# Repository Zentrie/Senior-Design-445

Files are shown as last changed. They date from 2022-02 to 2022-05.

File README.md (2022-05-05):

# 445

An autonomous food container dispenser machine. 

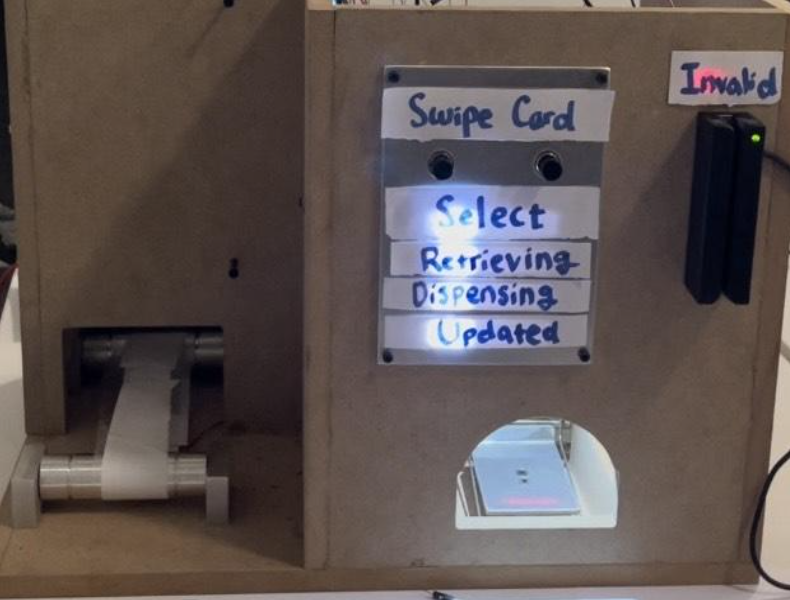
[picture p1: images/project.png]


Team Members:

Ariocie Liang (arliang2), John Kim (jaehank2), Henry Guan (henryg3)

## PROBLEM

Good2Go (G2G) containers are used all throughout dining halls for individuals wanting to take their food to go. The program allows you to trade in an old container for a token, where that token can then be used to trade for a new container. This is a hassle for both parties that handle the entire process. It's very redundant and can be streamlined/improved with mechanical assistance.

## SOLUTION

Our solution involves a token/food container swapping machine that serves 2 main functions:

Have a G2G token, that upon deposit, returns a clean container.
Accept a used container, returning a G2G token or a clean container.
The goal here is to make the process semi-autonomous by removing 2 stages of interaction, as well as speeding up the entire process by doing so.

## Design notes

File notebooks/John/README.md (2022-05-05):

<h1 align="center"> John Kim (jaehank2) Worklog </h1>

* [Summary](#summary)
* [Week of 2022-01-24](#week-of-2022-01-24)  
* [Week of 2022-02-01](#week-of-2022-02-01)  
* [Week of 2022-02-07](#week-of-2022-02-07)  
* [Week of 2022-02-14](#week-of-2022-02-14)  
* [Week of 2022-02-21](#week-of-2022-02-21)  
* [Week of 2022-02-28](#week-of-2022-02-28)  
* [Week of 2022-03-07](#week-of-2022-03-07)  
* [Week of 2022-03-14](#week-of-2022-03-14)  
* [Week of 2022-03-21](#week-of-2022-03-21)  
* [Week of 2022-03-28](#week-of-2022-03-28)  
* [Week of 2022-04-04](#week-of-2022-04-04)  
* [Week of 2022-04-11](#week-of-2022-04-11)  
* [Week of 2022-04-18](#week-of-2022-04-18)  
* [Week of 2022-04-25](#week-of-2022-04-25)  
* [Week of 2022-05-02](#week-of-2022-05-02)  
* [References](#references)

## Summary
This is a notebook outlining the work and progress I made from the start of the project. All the references used are attached under the [References](#references) section at the very bottom.

## Week of 2022-01-24
* **01/25 (Getting Started on the RFA)**:
  * <ins>Objectives</ins>: Get to know the team and familiarize with the problem statement that the team is trying to solve
  * <ins>Overview</ins>: Our team was trying to automate a currently existent service used at the U of I dining halls. However, I was not too familiar with the current system and thus had to search online for how exactly the Good2Go system was managed and what problems there were. I realized that the current system required students to first receive a physical token and find a dining hall employee to exchange it for a new take-out container. After identifying the problems, I started working on the RFA (request for approval) to get started on our project.

## Week of 2022-02-01
* **02/01 (RFA Submission and Starting on Proposal)**:
  * <ins>Objectives</ins>: Get the RFA approved and start working on the proposal
  * <ins>Overview</ins>: The initial RFA post got rejected mainly because our team was not specific about the subsystem requirements. My team and I had a discussion with a TA named Dean Biskup to identify what we were missing in the RFA. I had a general idea of what kind of modules we were going to need for the project such as a motor, ID verification method, UI interface, and power supply components, the specifics were missing out as to how to integrate the entire components. I started looking into the details of each subsystem and was able to design an abstract FSM (finite state machine) with specific modules such as the QR scanner, scale, two sets of motors, display and a card reader. Additionally, I started outlining the criterion of success for our project, which required:
    1. Storing the tokens digitally for each user
    2. Allowing exchange between not only tokens for new containers but also old containers for new containers

## Week of 2022-02-07
* **02/07 (Complete and Submit Proposal)**:
  * <ins>Objectievs</ins>: Complete the proposal for submission
  * <ins>Overview</ins>: Even after getting the RFA approved, the proposal required extra work from each member. I was responsible for the design as well as the tolerance analysis. Our project required a mechanism to dispense exactly one container upon a single request, and the design that I came up with was to have two mechanical arms retracting in a order shown in the image below to dispense a single container while reloading the other containers.  
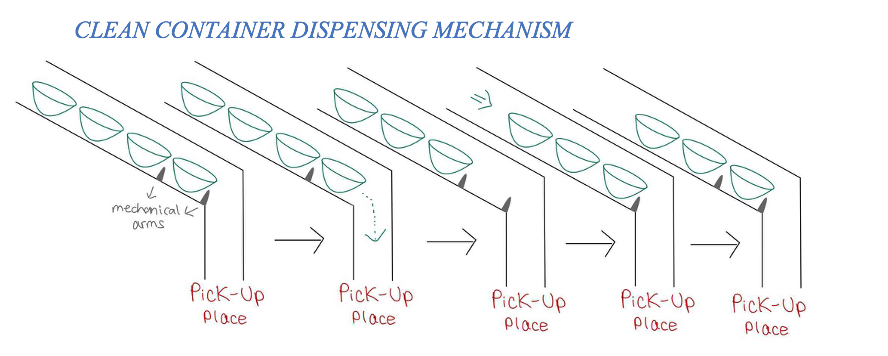
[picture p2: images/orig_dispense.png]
  &nbsp; &nbsp; 

&nbsp; &nbsp; &nbsp; &nbsp; &nbsp; &nbsp; &nbsp; &nbsp; The design for the retrieval system required the machine to parallelize the sensor validtion process with the control subsystem. This was  
&nbsp; &nbsp; &nbsp; &nbsp; &nbsp; &nbsp; &nbsp; &nbsp; to allow the machine to retrieve a returned container the moment it finished validating the container, and thus I made a design to have  
&nbsp; &nbsp; &nbsp; &nbsp; &nbsp; &nbsp; &nbsp; &nbsp; two mechanical arms attached beneath the scale to lift up upon a command from the microcontroller. The image below shows physical  
&nbsp; &nbsp; &nbsp; &nbsp; &nbsp; &nbsp; &nbsp; &nbsp; design of the retrieval system.

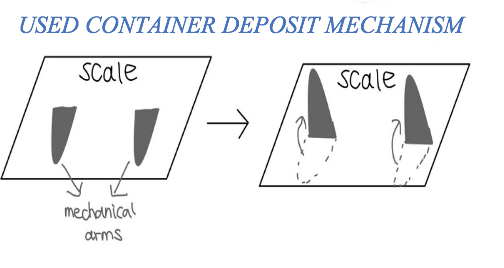
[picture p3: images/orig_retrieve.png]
&nbsp; &nbsp; &nbsp; &nbsp; &nbsp; &nbsp; &nbsp; &nbsp; 

&nbsp; &nbsp; &nbsp; &nbsp; &nbsp; &nbsp; &nbsp; &nbsp; The tolerance analysis was done on the motors using the below equation. Since our project requried a safe and accurate control  
&nbsp; &nbsp; &nbsp; &nbsp; &nbsp; &nbsp; &nbsp; &nbsp; mechanism of the motors, it required measurements on the angular position as well as the RPM (rotation per minute) of the two motors  
&nbsp; &nbsp; &nbsp; &nbsp; &nbsp; &nbsp; &nbsp; &nbsp; we were planning on using. The motor used for the retrieval system needed a closed loop feedback system to be able to rotate properly  
&nbsp; &nbsp; &nbsp; &nbsp; &nbsp; &nbsp; &nbsp; &nbsp; and the speed of the motor was controlled by sending different pulse data. 

&nbsp; &nbsp; &nbsp; &nbsp; &nbsp; &nbsp; &nbsp; &nbsp; 

* **02/11 (PCB Discussion)**:
  * <ins>Objectives</ins>: Discuss the components of the PCB and general pin layout
  * <ins>Overview</ins>: The PCB required getting the footprints of each module our team was planning on using. This meant that we had to decide on the specific modules we were planning on using to get an idea of what kind of pin layouts the schematic would use. There was still some confusion between the exact components we needed, and thus I had worked on finalizing on what materials we needed. All the power and ground wires (VCC and GND) were ignored in the above consideration and only the digital and analog pins are discussed below. Regardless of the model number, the push buttons as well as the motors were going to have 1 data pin. The QR scanner was going to utilize a UART serial communication using the RX (receive) and TX (transmit) pins. The load cell had its own pin layout from the datasheet, but required an amplifier that essentially used serial clock and one data pin. The card reader was going to be connected to the microcontroller through a USB cable, and the power supply was going to utilize a voltage regulator to convert from 12V to 5V. Lastly the LEDs needed 6 to 7 pins, so using a mux was able to cut down the pin numbers to have 3. The below image shows the final schematic layout with the footprints.

<p align="center">
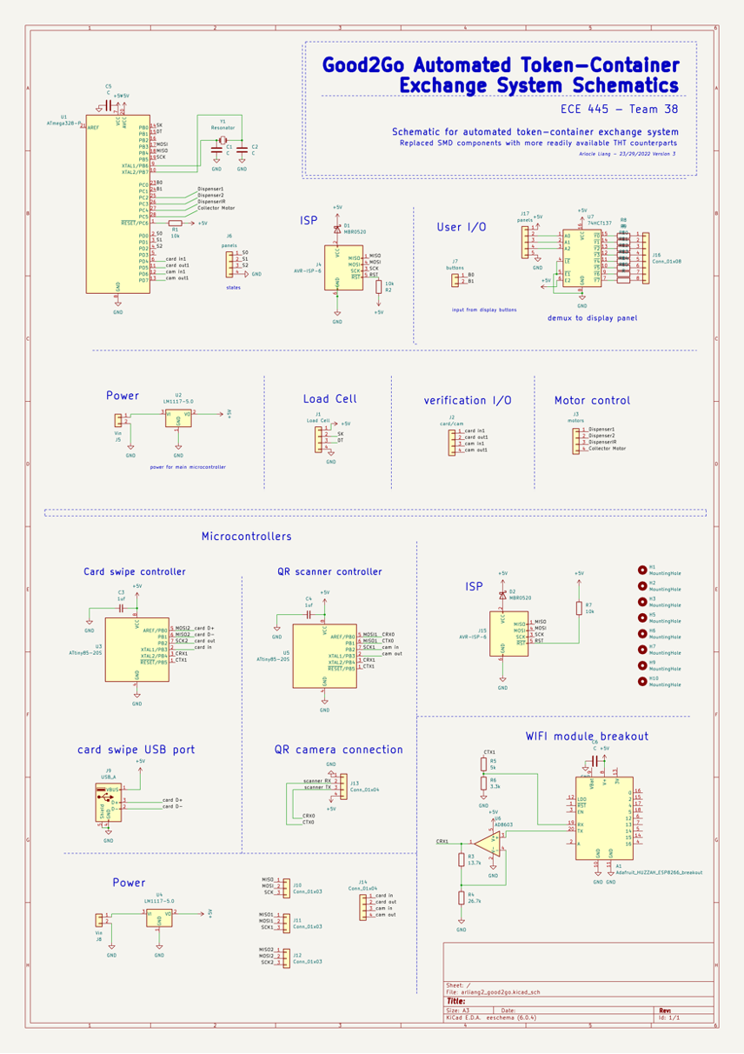
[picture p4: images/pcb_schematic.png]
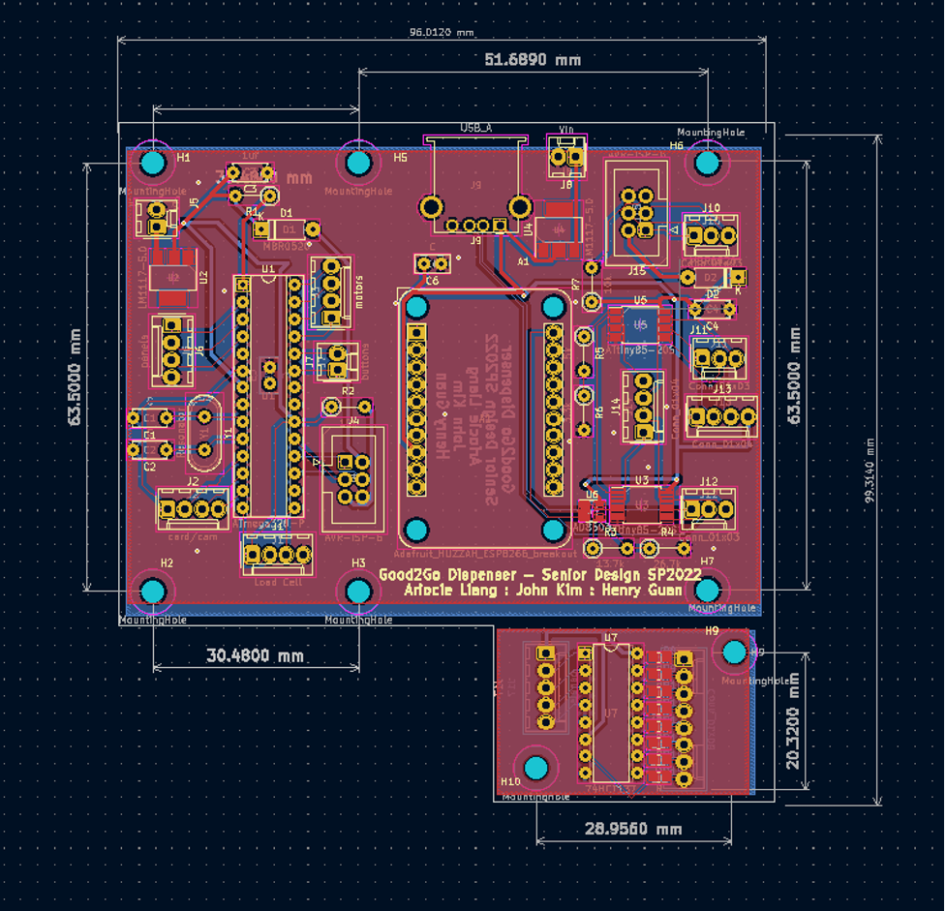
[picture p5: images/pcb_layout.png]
 &nbsp; &nbsp; &nbsp; &nbsp; &nbsp; 
</p>

<p align="center">
 <strong>PCB Layout (Left), PCB Schematic (Right)</strong>
</p>

## Week of 2022-02-14
* **02/16 (Design Document)**:
  * <ins>Objectives</ins>: Finish writing design document for initial submission
  * <ins>Overview</ins>: This week, I mainly focused on writing several parts of the design document. Not only did I add more details for each subsystem and incorporate the design changes we made as a team, but also worked on the Requirements and Verification table. A lot of the requirements for the project required correct mechanical execution that heavily depended on the software code. Thus, some of the verification methods included utilizng the serial monitor for debugging purposes.

## Week of 2022-02-21
* **02/21 (Design Document Check)**:
  * <ins>Objectives</ins>: Check the initial design document submission with our TA
  * <ins>Overview</ins>: After the initial submission of our design document, we received feedback on both the writing requirements as well as the technical aspects. There were a few grammatical errors, but it was mostly about the entire structure of the paper. I revised the format of the document to follow the example paper given on the course website. Additionally, the tolerance analysis needed a bit more work as now I realized that the angular position required to go beyond 90 degrees regardless of the RPM to correctly retrieve the returned container.

* **02/23 (Changes to Design Document)**:
  * <ins>Objectives</ins>: Final submission of design document
  * <ins>Overview</ins>: Made the final changes outlined during the design document check and went over all the small writing details such as the TOC (table of contents) and paging rules. The block diagram also needed changes as we had to specify whether the type of data line was digital or analog. The power supply lines also need specifications as to what voltage it required (e.g. 12V or 5V or 3.3V). The below block diagram reflects the final changes made.

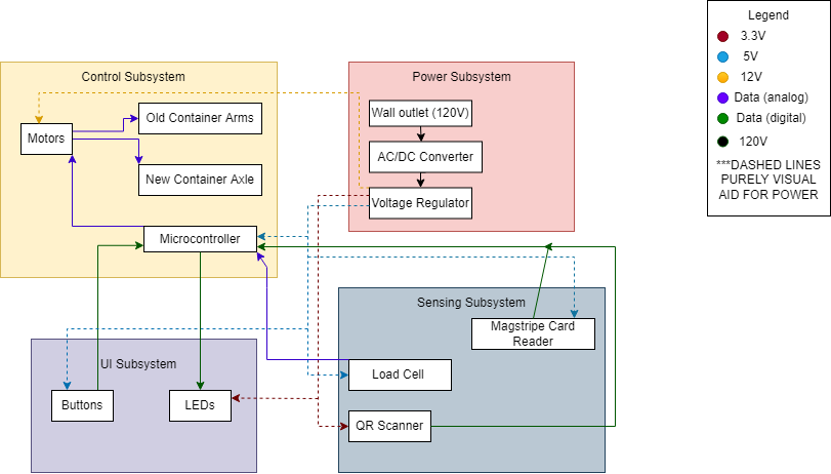
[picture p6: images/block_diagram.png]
&nbsp; &nbsp; &nbsp; &nbsp; &nbsp; &nbsp; &nbsp; &nbsp; 

* **02/27 (PCB Parts)**:
  * <ins>Objectives</ins>: Finalize on PCB parts
  * <ins>Overview</ins>: After acquiring the footprints of each module for the PCB schematic, we had to order the right parts to actually connect to the PCB components. I went through a lot of design considerations such as between servo and stepper motors. In the end, I decided on certain parts like the continuous and non-continuous servo motors as well as acquiring a specific barcode/QR scanner from WaveShare.

## Week of 2022-02-28
* **03/04 (Software Motor Code)**:
  * <ins>Objectives</ins>: Start on writing the software code for motors
  * <ins>Overview</ins>: Because we were dealing with two different types of servo motors (continuous and non-continuous), they were operating in different modes and thus needed different code to run the two. As most of the parts were currently not available for actual testing because they were either still being shipped or being used by the machine shop for the physical design, I had written code for simply testing whether the motors were working or not. The two peices of code that I ran were based on position data and pulse data. This is when I realized we had a malfunctioning continuous motor as it wasn't even getting powered on. I notified my team members and ordered a new component.

## Week of 2022-03-07
* **03/07 (Finish Pseudocode)**:
  * <ins>Objectives</ins>: Finish Pseudocode for the entire project with all sensors
  * <ins>Overview</ins>: Even after getting the individual components working, integrating would add a lot of changes to the written code and so I decided to first work on the general state machine of the project. This way, all the code that I would write for each control and sensor module would take into account the type of input and output they need to be receiving and sending. The below image that I made shows the different state transitions. The initial state corresponds to the idle state of the machine waiting for a card swipe. Only then would the machine activate and start executing other exchange processes.

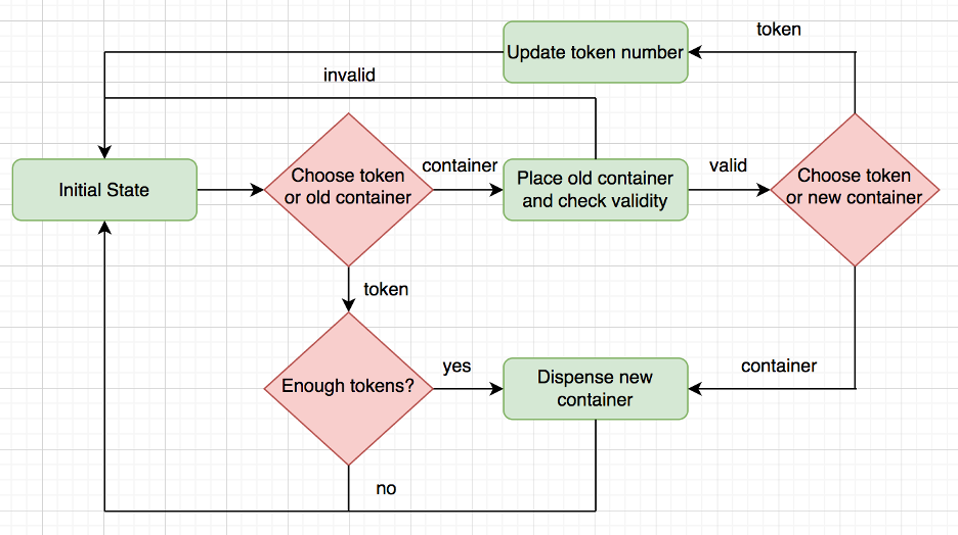
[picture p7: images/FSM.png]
&nbsp; &nbsp; &nbsp; &nbsp; &nbsp; &nbsp; &nbsp; &nbsp; 

* **03/10 (Machine Shop Design)**:
  * <ins>Objectives</ins>: Provide design schematic for the machine shop
  * <ins>Overview</ins>: Since our project was creating a physical product without any basis to automate a currently existing service, there were complex design schematics we had to create to hand off to the machine shop. Only then would they be able to actually build what we had intended. I started looking into the specs of the different modules we bought as these were critical in determing the exact orientations and placements of the sensors. For example, the QR scanner required a specific tilt tolerance and limited FOV (field of view). Also since our machine had to be downscaled compared to what we had originally planned, we had to effectively make use of the space. The below diagram shows the design specifications my team and I made for the machine shop.

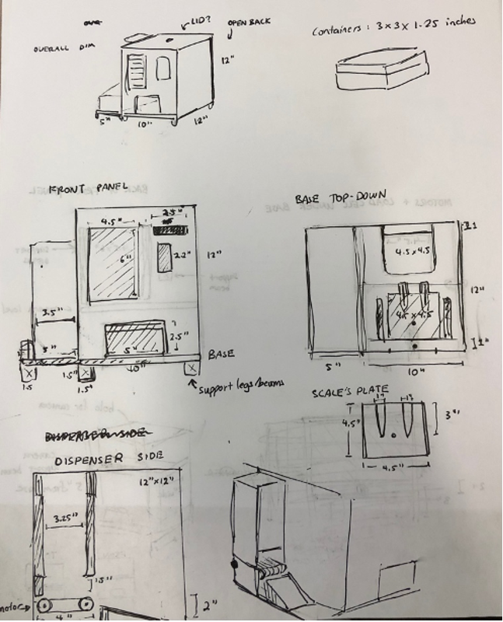
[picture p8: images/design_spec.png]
&nbsp; &nbsp; &nbsp; &nbsp; &nbsp; &nbsp; &nbsp; &nbsp; 

## Week of 2022-03-14
* **03/15 (Finalizing on Parts)**:
  * <ins>Objectives</ins>: Finish ordering all parts required for the project
  * <ins>Overview</ins>: After buying all the big components of the project including the QR scanner, card reader, load cell, and motors, there were still a few other elements we needed. We had to buy different types of LEDs for the status messages as well as an amplifier as the load cell may give out weak signals that are hard to perform a digital read on.

* **03/17 (Machine Shop Order Check)**:
  * <ins>Objectives</ins>: Give all components needed to machine shop for completion of the physical design
  * <ins>Overview</ins>: Despite the design schematic with all specs labeled out, the machine shop required all components in hand to completely finish off the physical design. Thus the continuous motor that I had found defective had arrived this week, and needed to hand that off along with the LEDs to get our actual design finished. The below images show what our machine looked like right after the machine shop had finished making it.

<p align="center">
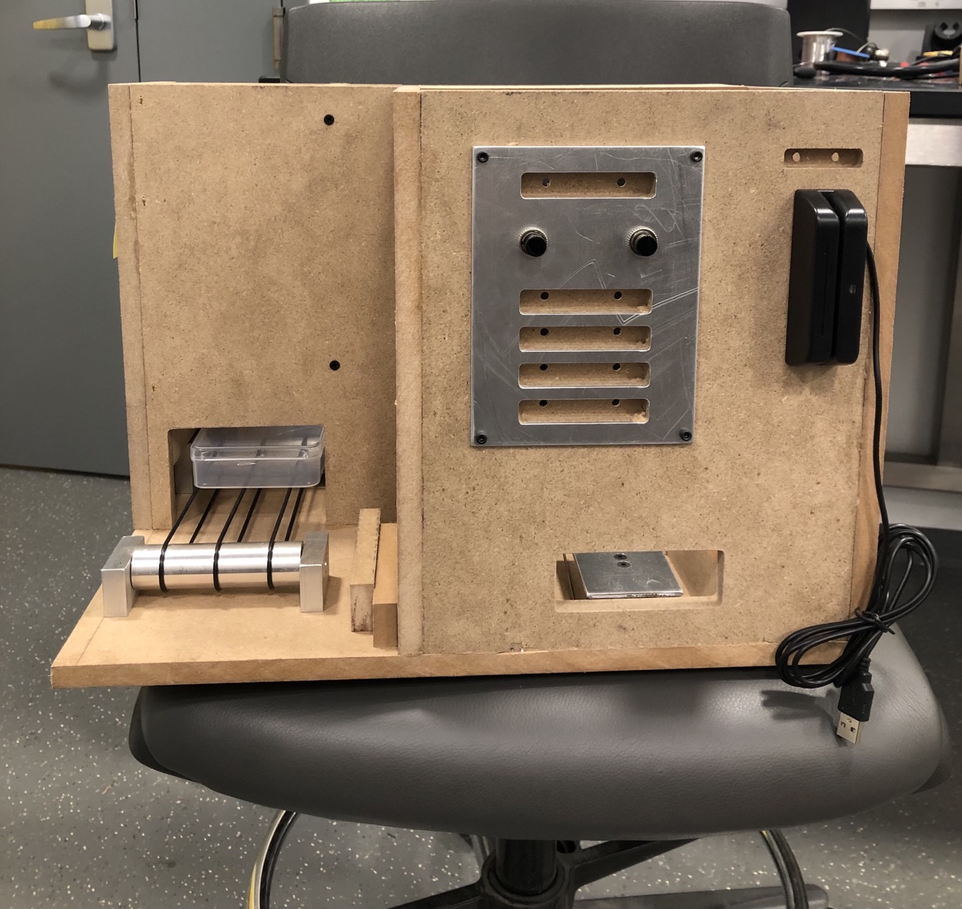
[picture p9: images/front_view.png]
 
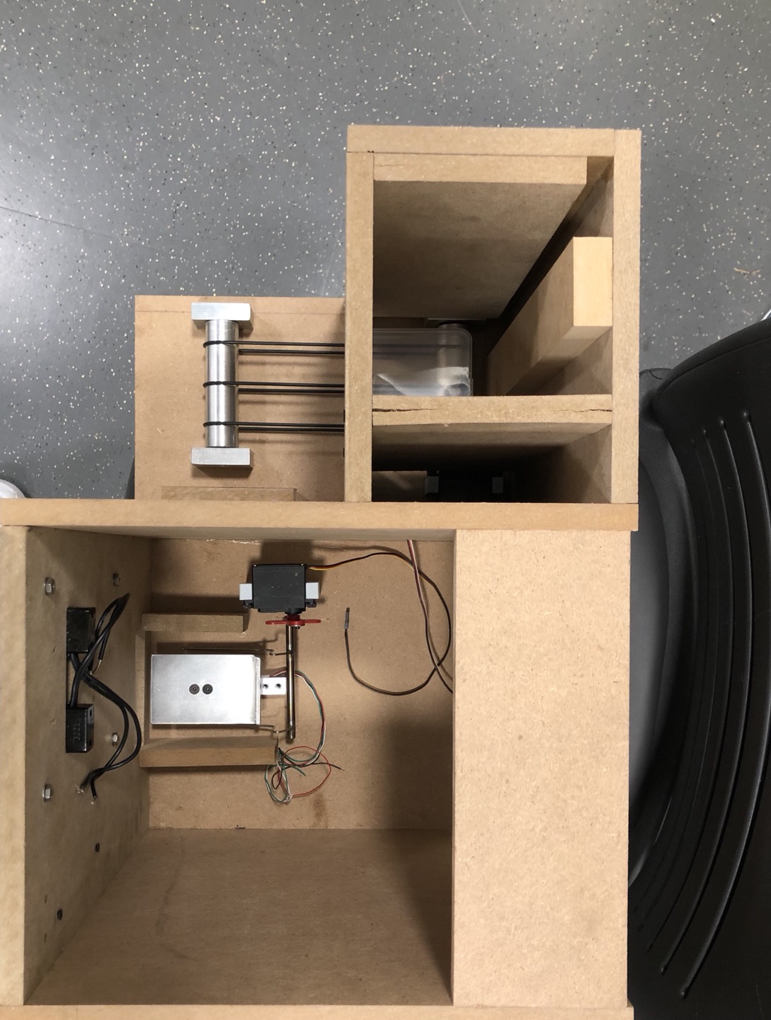
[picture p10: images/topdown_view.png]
 
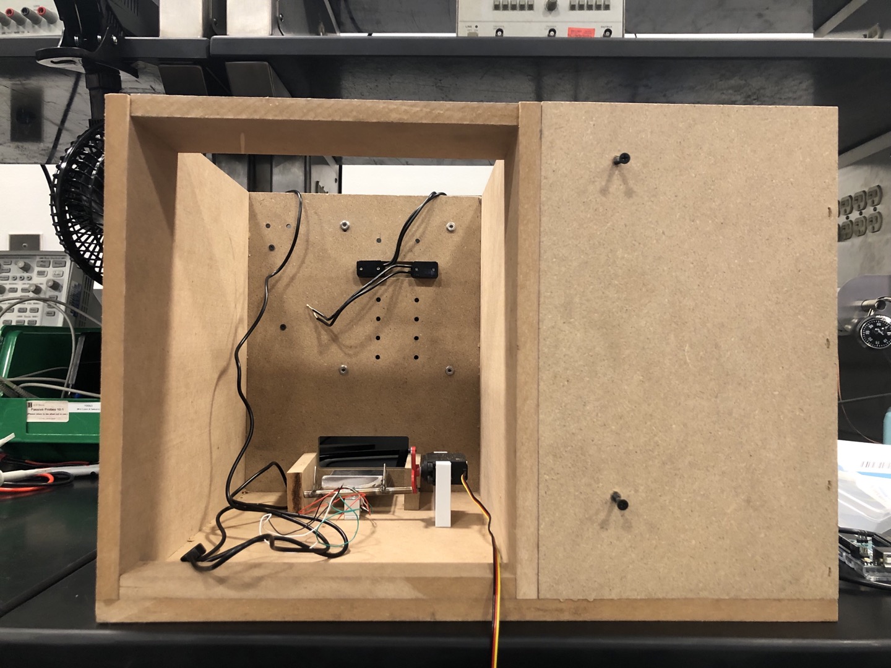
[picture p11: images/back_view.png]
 
</p>

<p align="center">
 <strong>Front View (Left), Top-down View (Center), Back View (Right)</strong>
</p>

## Week of 2022-03-21
* **03/21 (Software FSM Code)**:
  * <ins>Objectives</ins>: Finish the pseudocode for FSM
  * <ins>Overview</ins>: The individual modules still required their own code to actually work, but I made separate helper functions corresponding to different sensor modules. Thus whenenver the FSM required a certain execution of a module, I would call the appropriate functions (e.g. QRread()) that were at this point in time void functions without any lines of code. The FSM code was written first to get an idea of the logic flow and which tasks had higher priority compared to others.

* **03/26 (PCB Testing & Revision)**:
  * <ins>Objectives</ins>: Testing and revising the PCB order
  * <ins>Overview</ins>: I tried helping out with some of the PCB testings while mainly working on the software side. I realized that despite the individual software testing that I have been doing using Arudino uno and a USB host shield, the PCB had to achieve its full functionality as soon as possible to be incorporated into our project. I mainly helped out with soldering the parts and also probing each component to see if there were any faulty chips or wrong connections made within the board itself.

## Week of 2022-03-28
* **03/28 (Individual Progress Report):**
  * <ins>Objectives</ins>: Work on individual progress report for submission
  * <ins>Overview</ins>: I put a short pause on the software and pcb work to work on writing up my individual progress report. This report includes all the personal work I had done so far along with some of the software code I had written.

* **03/29 (Software Servo Motor Code)**:
  * <ins>Objectives</ins>: Finish the code for both continuous and non-continuous servo motors
  * <ins>Overview</ins>: Now that I had the initial code written for both the FSM and the motors, I worked on finishing up the codes for the motors to actually work with the intended design of our machine. The requirement was that the non-continuous motor that was responsible for the retrieval system required angular position data as well as the speed at which it rotates. Initially I had tried getting the motor to rotate slighly below 90 degrees with fast speed to "throw out" the returned containers but turned out to be a bit unsuccessful as it was getting too unsafe. The final testing gave a good result for rotating to 110 degrees witha delay of 10ms for each positional write. </br> </br> The continuous motor, on the other hand, had to go through some tuning process. Although sending a pulse of 1.5ms should have technically stopped the motor, it wasn't doing so and thus I used an adjustment screw and a potentiometer with PWM (pulse width modulation) to find the exact pulse for stopping. I also had to adjust the duration in which the continuous motor ran as it didn't have any closed loop feedback system. The below image shows the piece of code for the above behaviors. 

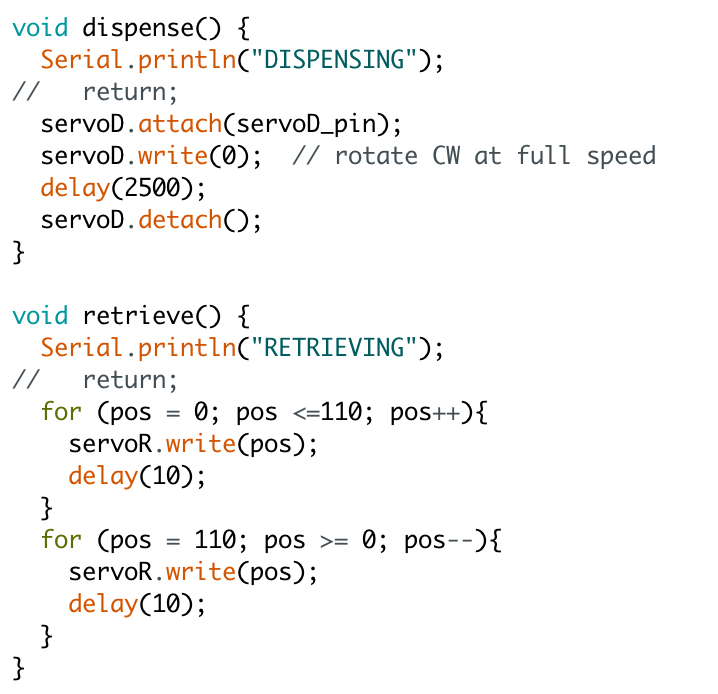
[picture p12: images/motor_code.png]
&nbsp; &nbsp; &nbsp; &nbsp; &nbsp; &nbsp; &nbsp; &nbsp; 

* **04/02 (Software Push Button Code)**:
  * <ins>Objectives</ins>: Software code for the two push buttons
  * <ins>Overview</ins>: The two push buttons that we were using for the project was slightly different than the normal push buttons with 4 legs. The push buttons that we had only had two legs and were operating in maintain-contact mode. This meant that the push button maintained whatever status it was before until another press was made. For example, the data pin for the push button will continuously read OFF (0) until a press is made at which the pin will now continuously read ON (1). The code was written such that it registers the initial button press and only measures the change in the states when needed. This method allowed other processes with higher priority such as the USB task and the UART communication to run without any delay.

* **04/03 (Hardware Push Button)**:
  * <ins>Objectives</ins>: Push Button Issue and Hardware
  * <ins>Overview</ins>: One problem with the push buttons was that the two legs had different types of wires, and needed extra soldering to fit into our PCB. I had notified my teammates about this and was able to get a small board layout to add different wires for the push buttons. The testing of the push buttons were done through a serial monitor to constantly check for the pressed state. However one major issue that I faced was that the buttons were left in a floating state and thus had to add a pull up resistor to define the logic states of the two buttons. The right image below shows the faulty behavior I got, and the left image shows the correct behavior of switching states upon a press.

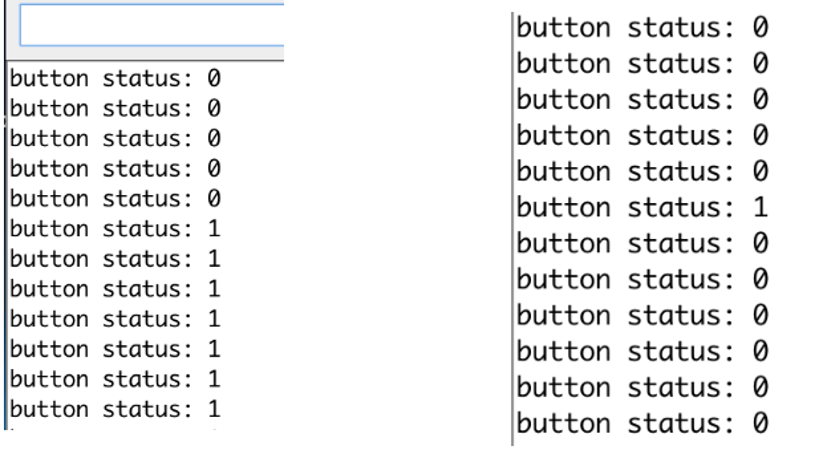
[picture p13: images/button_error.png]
&nbsp; &nbsp; &nbsp; &nbsp; &nbsp; &nbsp; &nbsp; &nbsp; 

## Week of 2022-04-04
* **04/04 (Software Motor Debugging)**:
  * <ins>Objectives</ins>: Non-continuous servo motor debugging
  * <ins>Overview</ins>: When running my software code on our actual machine, I started noticing a weird behavior of one of the motors that we were using when powered up. The normal executions of the motors were fine, but only in the beginning, the motor would shoot up to a 90 degree position when we required it to stay at 0 degrees until it received commands from the microcontroller. After doing some searching, I found out that the motors drew a lot of power and thus required a separate power supply. The solution that I came up with was to have another battery pack of 5V and also add a capacitor in the circuit. Lastly, I sent some initial data commands to the motors on start up to ensure no erratic behaviors were made.

* **04/07 (Software Load Cell Code)**:
  * <ins>Objectives</ins>: Software code for load cell
  * <ins>Overview</ins>: I started working on the software code for the load cell, and realized I had to go through some calibration process. Most scales already come with the calibration done, but the load cell itself had to be manually calibrated for accurate weight measurements. Since our machine had to weigh very light food containers, the below code was written with the use of an amplifier to adjust the calibration factor. The process included placing a known weight onto the load cell and constantly adjusting the calibration factor until the measurement was within a small margin of error.

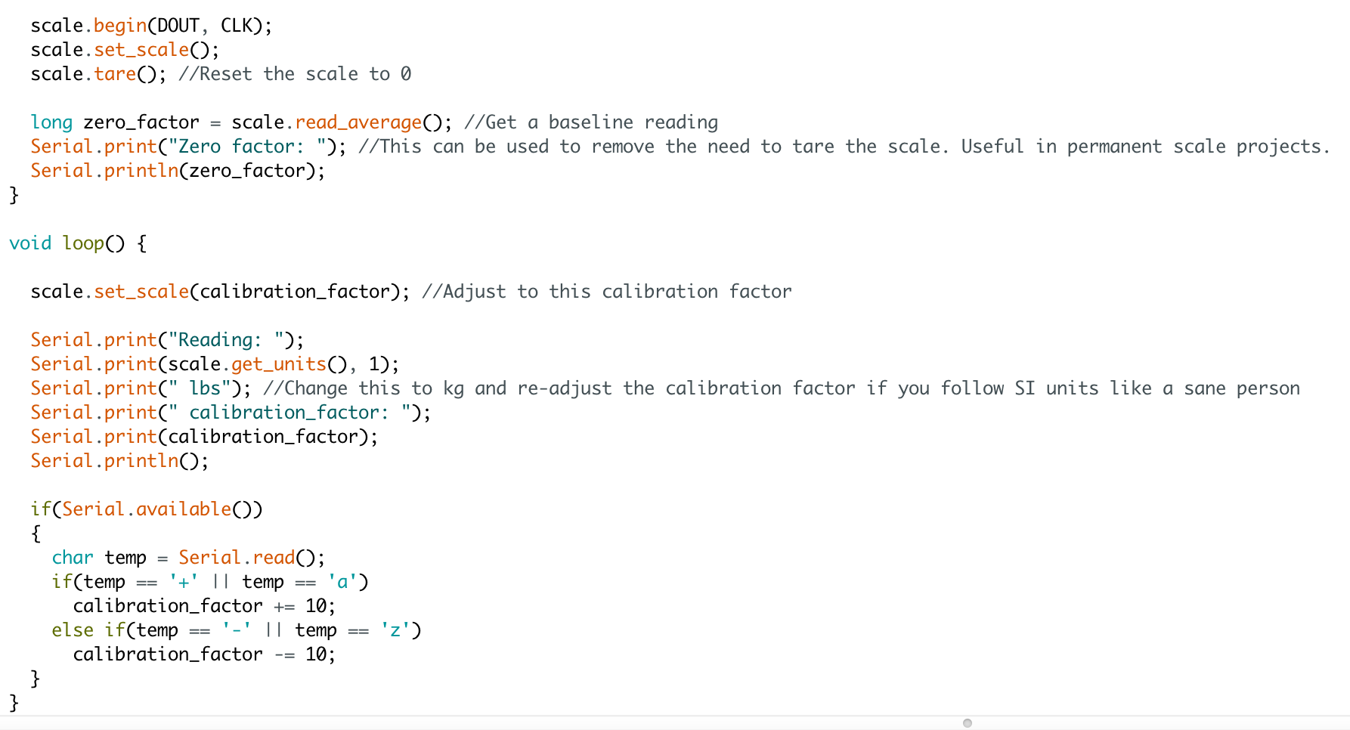
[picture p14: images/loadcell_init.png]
&nbsp; &nbsp; &nbsp; &nbsp; &nbsp; &nbsp; &nbsp; &nbsp; 

* **04/08 (Software Load Cell Code)**:
  * <ins>Objectives</ins>: Software code for load cell continued
  * <ins>Overview</ins>: After the initial calibration was completed, I started working on actual weight measurements within the software. Since the load cell was calibrated for reading small weights, even small small pressure onto it by human contact made extreme fluctations for the readings. Thus I had introduced some delay in the loadcell measurement to start reading weight data until the returned container was fully placed and succeeded in the QR scanning. I then averaged out the weight readings to get an accurate measurement.

* **04/09 (Software Load Cell Complete and Starting QR Code)**:
  * <ins>Objectives</ins>: Load cell wrap up and starting on software code for QR
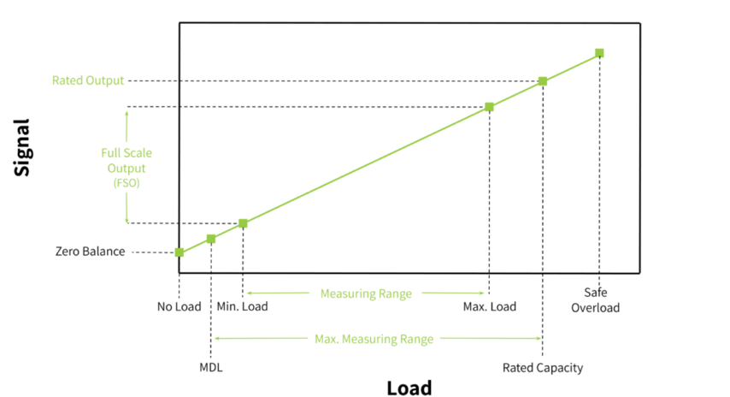
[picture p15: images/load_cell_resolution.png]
  * <ins>Overview</ins>: The last part of the loadcell code required coming up with weight thresholds for the validation process. We required that the returned container shouldn't contain too much food waste. Thus if the container weighed more than 7g compared to its base weight, we would have to reject the container. I set a weight threshold of 10g as the base weight of the container turned out to be approximately 3g. The exact resolution of the loadcell directly links to the sensitivity and accuracy. Thus using the graph below, I was able to calculate the minimum weight measurable by dividng the maximum load by the number of divisions to get about 0.03g. </br> &nbsp; &nbsp; &nbsp; &nbsp;   </br> The QR scanner module supported UART serial communcation. Thus I had to make a connection between the RX (receive) and TX (transmit) pins between the host (microcontroller) and the device (QR scanner). After some trial and error, I was actually able to get some raw readings of the QR scans.

## Week of 2022-04-11
* **04/11 (Software QR Complete)**:
  * <ins>Objectives</ins>: Complete software code and testing for QR scanner
  * <ins>Overview</ins>: Even though I was able to get the QR code readings using the module, there were several issues that I had to fix. One was that the reading values kept changing even for the same QR code. I realized that there were two different types of QR codes, dynamic and statc. Dynamic QR codes had their encoded information change upon creation as it was a redirection to a URL whereas static QR codes had their information fixed. Since our project only required QR codes for validation of the G2G containers, I used static QR codes to read the data. Another issue was that if the returned container sat in the return place for too long, it would get multiple QR scans and fill up the serial communication buffer. Thus next time the machine was used, it gets tricked into thinking that it already has a valid QR scan. To solve this issue, I had to clear the buffer if and only if the container was invalid. I also had to send several UART scan commands to the address of the QR to change some of the default behaviors that were incompatible with the intended design of our project. First change was to set the baud rate from 9600 to 115200 to be synchronized with the card reader, and next was changing the scan mode from sleep to continuous scanning mode. Last step was setting a manual timeout value of 10 seconds to allow users ample time to place and return an old container. After all these configurations, the below code shows what I had used to read in QR data.

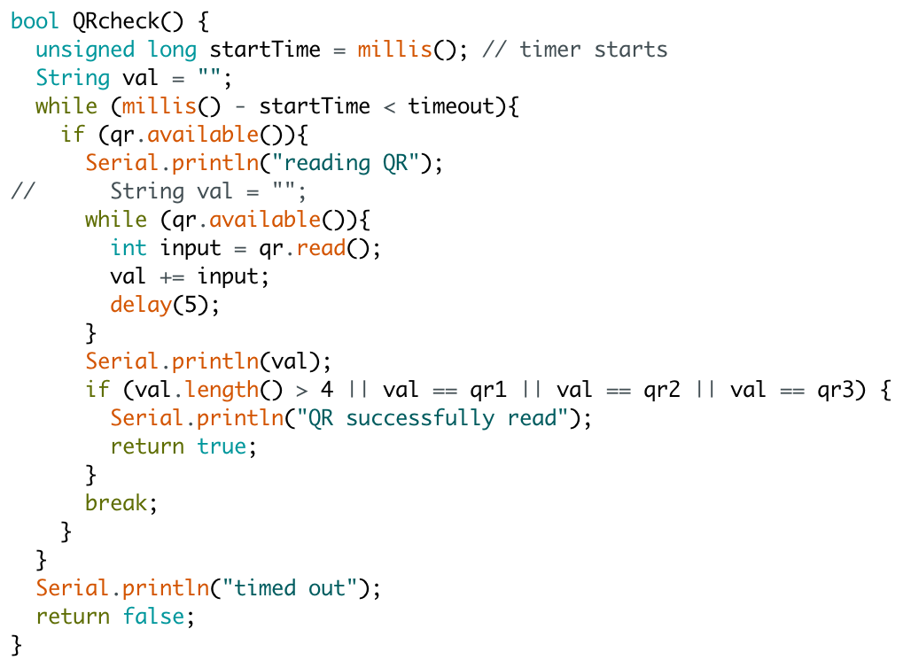
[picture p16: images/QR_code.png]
&nbsp; &nbsp; &nbsp; &nbsp; &nbsp; &nbsp; &nbsp; &nbsp;  

* **04/12 (Software Card Reader Code)**:
  * <ins>Objectives</ins>: Software code for usb magnetic card swiper
  * <ins>Overview</ins>: I started working on the card swiper but spent numerous hours just debugging to get it to work. This was because the card reader was a HID device and had complex USB protocols that I had to go through. The initial model we were using was a MSR123 card reader. As it failed to initialize, I started looking into the product ID as well as the vendor ID and saw a mismatch between what my computer had detected and what my software code had detected. It was failing to retrieve the device descriptor for the specific USB device. I tried making tweaks in the code to store larger bits for the ID as there was a huge mismatch, but no sort of available driver code was able to get the card initialized.

* **04/13 (Card Reader Code Failure & Debugging)**:
  * <ins>Objectives</ins>: Final debugging of the card reader
  * <ins>Overview</ins>: After multiple attempts, I went line by line within the Arduino library to find the point of failure, and identified it to be in the below code. When I declared a USB object within the software, it went through a list of initialization processes to find the device descriptor and storing the end-point address of the device. However it was unable to do so, and I realized that I either had to write a separate driver code (which was impossible with the time constraint I had) or find another HID device compatible with existent driver codes.

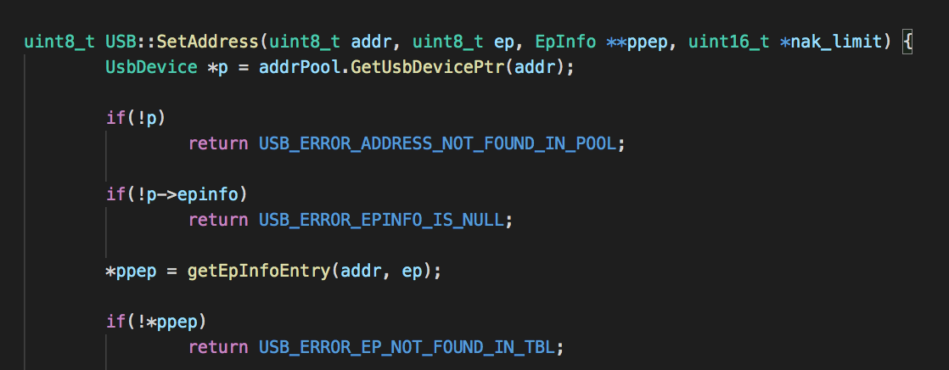
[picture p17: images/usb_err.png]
&nbsp; &nbsp; &nbsp; &nbsp; &nbsp; &nbsp; &nbsp; &nbsp;  

* **04/14 (Card Reader Alternative Solution)**:
  * <ins>Objectives</ins>: Design consideration for the card reader
  * <ins>Overview</ins>: After multiple failures with the card reader, I started thinking about different alternatives. Many teams have been using a RFID tags for ID verification and I also thought about moving to this method. However not only did this incur additional cost as well as delaying the progress with delivery time, it didn't accomodate the intended design of our machine as we wanted it to be available exlcusively to the U of I students using their iCards. Using RFID cards meant that the project was just a proof of concept that has very little practical use as it meant all students would have to purchase a RFID tag. Thus I decided to stick with a card swiper but looked for different models.

* **04/15 (Card Reader MSR90)**:
  * <ins>Objectives</ins>: Card reader code using MSR90
  * <ins>Overview</ins>: The unsuccessful attempts with MSR123 led me to try with another model called MSR90. Forunately after some tweaking, I was able to get the card reader to initialize. One major modification I had to do was so that it would read all different kinds of magnetic stripe cards, but only parse the data for iCards (and not credit cards, etc). This was done by modifying the interrupt response of the device. Card readers act similar to USB HID Keyboard device descriptor as it responds to both key up and key down interrupts. The image below shows the different interrupts that a card swipe and keyboard responds to. The card reader also responded to presses of special key characters like SHIFT and CAPS, which wasn't what I wanted for the project. Magnetic cards usually have three tracks and each track is separated by some special character, which was why the interrupt was happening for RIGHT SHIFT and so on. After getting rid of some of the interrupts, I was able to read in actual data from each card swipe.

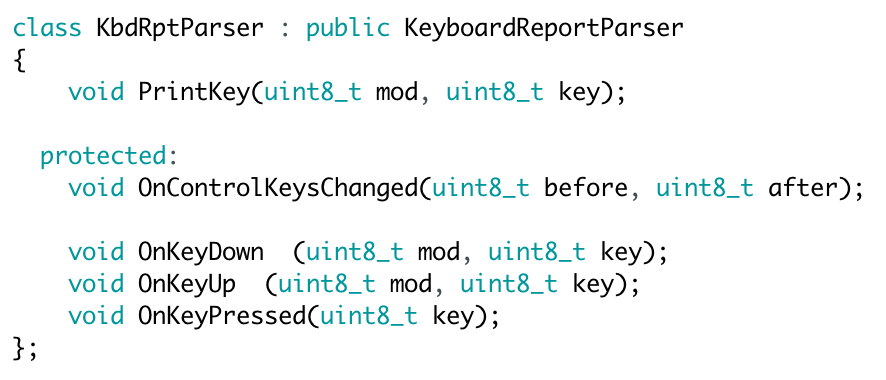
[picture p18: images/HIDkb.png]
&nbsp; &nbsp; &nbsp; &nbsp; &nbsp; &nbsp; &nbsp; &nbsp;  

* **04/16 (Software Card Reader Complete)**:
  * <ins>Objectives</ins>: Finish up the software code for magnetic card reader
  * <ins>Overview</ins>: The last step of the card reader required data parsing. Because the card swipe was sending three different tracks of information, I had to identify which track was relevant and which data to parse. After the final parsing I was able to identify each iCard swipe to be of a CARDHOLDER/UNIVERSITY card as well as reading in the UIN (unifersity identification number).

* **04/17 (Software Code Integration)**:
  * <ins>Objectives</ins>: Integrate all software codes
  * <ins>Overview</ins>: After individual testing of each module, I had to put these back into the original FSM code that I had written to get the entire functionality of the machine working. Since we were using on-chip memory to store user information such as the number of available tokens, I created a student struct for each user as below. Each student is identified by his or her UIN along with the name, and the data stores the number of tokens as well. The final integration and output of our machine is posted on YouTube, and the link is shown under 04/24 (Final Wrap Up and Enclosure) in section [Week of 2022-04-18](#week-of-2022-04-18).

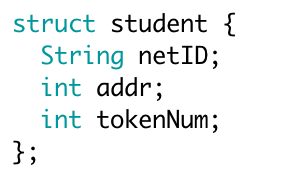
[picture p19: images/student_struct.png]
&nbsp; &nbsp; &nbsp; &nbsp; &nbsp; &nbsp; &nbsp; &nbsp;  

## Week of 2022-04-18
* **04/19 (LCD Display and LED)**:
  * <ins>Objectives</ins>: Design decision between LCD and LEDs and finish software code for status messages
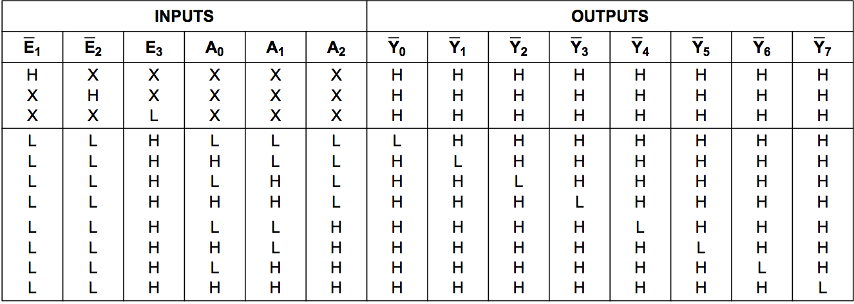
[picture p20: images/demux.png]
  * <ins>Overview</ins>: Initially I thought of having a LCD display screen for UI subsystem, but realized that the machine was intended to behave in a similar manner to that of a normal vending machine, which meant that there was little to no information to convey to users. Most information was abstracted away for security reasons and thus the final design decision I made was using LED status messages. This was done using LEDs for 6 different states and using a multiplexer to cut down on the number of wires. The table below shows the 8-to-1 demux outputs based on the three select pins A0, A1, A2. </br>   </br> The LEDs were then controlled within the code using a helper function shown below.

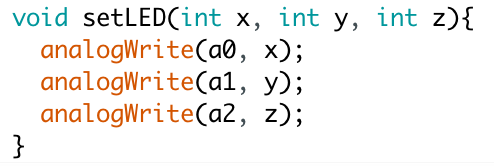
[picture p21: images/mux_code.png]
&nbsp; &nbsp; &nbsp; &nbsp; &nbsp; &nbsp; &nbsp; &nbsp;  

* **04/22 (Mock Demo)**:
  * <ins>Objectives</ins>: Mock demonstration with our TA
  * <ins>Overview</ins>: We did our mock demosntration just in front of our TA and received feedback on certain parts. We were told to have an enclosure for our machine so that all components are well hidden from an outside user. The functionality was mostly achieved, but there were some minor things that I still had to work on.

* **04/23 (Final Debugging and LED Status Message)**:
  * <ins>Objectives</ins>: Finalize and complete on the functionality part of the project
  * <ins>Overview</ins>: Most of the software and hardware components were complete at this point, and I had to ensure that everything was working as expected for the final demo. I ran through several different testcases for our machine and also wrote the status messages on top of the LEDs.

* **04/24 (Final Wrap Up and Enclosure)**:
  * <ins>Objectives</ins>: Finalize and complete the entire project
  * <ins>Overview</ins>: Incorporating the feedback we received from the mock demo, we completed the enclosure for our machine so that all things were abstracted away. We also made certain openings for the enclosure so that any "authorized" individuals were allowed to collect returned containers and refill new containers. The below link shows the functionality of our entire project and the two gifs below demonstrate how the sensor and control subsystem work together to complete the retrieval and dispensing system.
  * <ins>YouTube link</ins>: https://www.youtube.com/watch?v=p8fdRb78moU

<p align = "center">


</p>

<p align = "center">
 <strong>Retrieval (Left) and Dispensing (Right)</strong>
</p>

## Week of 2022-04-25
* **04/26 (Final Demo)**:
  * <ins>Objectives</ins>: Complete final demonstration
  * <ins>Overview</ins>: We did our final demonstration in front of our TA, professor Song as well as some other individuals who wanted to attend our presentation.

* **04/27 (Presentation Slides)**:
  * <ins>Objectives</ins>: Work on presentation slides and final report
  * <ins>Overview</ins>: After the final demo was over, there were only two major components left, which were the final presentation and the final report. I took this week to complete some of the design and software components for both the presentation and the report. I also arranged our team meetings to get together and rehearse.

## Week of 2022-05-02
* **05/03 (Final Presentation)**:
  * <ins>Objectives</ins>: Deliver our final presentation
  * <ins>Overview</ins>: Similar to the final demo, we had our final presentation in front of our TA, professor Song, and some individuals who wanted to attend. This took about 20 minutes along with 5 extra minutes for additional Q&A.

## References
* Adafruit, Continuous Rotation Servo - FeeTech FS5103R. [Online]. Available: https://media.digikey.com/pdf/data%20sheets/adafruit%20pdfs/154_web.pdf. [Accessed: 02-May-2022].
* “QR code vs Barcode: Why the difference matters,” Paysley Blog, 10-Feb-2022. [Online]. Available: https://paysley.com/blog/qr-code-vs-barcode/. [Accessed: 03-May-2022].
* “Resistors for led circuits: Resistor applications: Resistor Guide,” EEPower. [Online]. Available: https://eepower.com/resistor-guide/resistor-applications/resistor-for-led/#. [Accessed: 03-May-2022].
* “RFID scanner - full tutorial,” Arduino Project Hub. [Online]. Available: https://create.arduino.cc/projecthub/shubamtayal/rfid-scanner-full-tutorial-6518db. [Accessed: 03-May-2022].
* “Stepper vs Servo,” Tutorial: Stepper vs Servo. [Online]. Available: https://www.amci.com/industrial-automation-resources/plc-automation-tutorials/stepper-vs-servo/. [Accessed: 03-May-2022].
* “Tal221 miniature load cell - cdn.sparkfun.com.” [Online]. Available: https://cdn.sparkfun.com/assets/9/9/a/f/3/TAL221.pdf. [Accessed: 02-May-2022].
* University Housing, “Good2Go carry-out program,” University Housing. [Online]. Available: https://housing.illinois.edu/Dining/Locations/Good2Go-Carry-Out-Program. [Accessed: 30-Apr-2022].

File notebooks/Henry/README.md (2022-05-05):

# Henry Guan    
# 2022-01-25 -- Formation of Team, RFA, Initial Parts List
- Found group members to form a team, worked on the RFA, as well as formulating a basic parts list with teammates.  
# 2022-01-27 -- Initial RFA Post 
- Completed RFA with teammates and posted to Web Board for approval. RFA was rejected; took TA feedback into account and made revisions to the RFA accordingly. 
# 2022-02-01 -- Discussion with Dean Biskup (TA) 
- Discussed how we can get our project approved with Dean after the third class meeting. Made more revisions to RFA and posted it to the Web Board.  
# 2022-02-07 -- Project Proposal 
- Worked on the proposal with my teammates, creating the block diagram, problem statement, and the RV Tables.
# 2022-02-08 -- Github Repository 
- Created Github repository with my teammates, uploaded initial project files.
# 2022-02-09 -- Project Proposal 
- Completed remaining sections of the proposal and proofread everything afterwards.
# 2022-02-16 -- Design Document 
- Worked on the Design Document, revising the block diagram and the Requirements and Verification, and added more to the Introduction section. 
# 2022-02-21 -- Design Document Check 
- Had our design document check with Professor Schuh before our final design submission and design review. 
# 2022-02-23 -- Design Document 
- Took Professor Schuh's feedback into account and edited the different units, adding to the Requirements and Verification, as well as revising the block diagram and changing our scale to a load cell.  
- Helping out with figuring the circuit schematic with our MCU in our Control Subsystem. 
<p align="center">

</p>
<p align = "center">
<strong> Block Diagram </strong>
</p>

# 2022-02-28 -- Design Review 
- Thought about how the Design Review will go, delegating parts to each teammate for what to talk about, as well as how to address the different kinds of questions we can expect. 
# 2022-03-01 -- PCB Design & Reviews
- Met with my teammates to finalize our PCB footprint design, and incorporated feedback from the PCB Reviews with a TA.
# 2022-03-10 -- Machine Shop Design 
- Met with my teammates to revise machine shop design from the initial conversation. 
  - Agreed to downsize machine 
  - Modified dispensing mechanism from retracting mechanical arms to a conveyor belt
  
- Measured dimensions of our intended container of use, sketching and designing our new machine shop design around the container's dimensions.
<p align="center">

</p>
<p align = "center">
<strong> Physical Design Used for our Machine Shop Contraption </strong>
</p>

# 2022-03-11 -- Machine Shop & Parts
- Met with Gregg Bennett and Skee Aldrich to discuss our revised physical design and get it built. 
- Bought parts from the ECE Supply Center, specifically two servo motors (one continuous, one non-continuous), a demultiplexer, an ATMega328P, and LED diodes.  
# 2022-03-12 -- PCB Order
- Teammates and I agreed to independently order the PCB, as the first round deadline already passed by. 
# 2022-03-17 and 2022-03-21 -- Machine Shop 
- Met with Gregg Bennett to look at initial physical apparatus and left parts with Gregg to continue the build progress. 
# 2022-03-26 -- PCB Testing & PCB Revisions 
- All met up at the lab to complete PCB assembly by soldering all components in, and started to test the PCB.  
- We made a big mistake with the PCB, as we had a lot of wrong parts, particularly resistors, as they were not the right value we initially thought we needed for our PCB to be functional. 
  - We modified our PCB footprint design accordingly, preparing for secound round PCB orders.
- Ordered barcode/QR scanner camera module.
# 2022-03-28 and 2022-03-29 -- Individual Progress Report
- Worked on individal progress report.  
# 2022-04-04 -- Initial Testing 
- Met with John to test motor functionality within our physical apparatus.
- Ordered new continuous servo motor as our original unit was dead on arrival (DOA). 
- Looked into magnetic stripe cards and how data is processed and sent through an MSR 123 USB reader. 
- https://www.tutorialspoint.com/arduino/arduino_dc_motor.htm -- Tried following this tutorial
- https://www.arduino.cc/reference/en/libraries/magstripe/ - Went through some of the libraries for magstripe card readers
# 2022-04-05 -- Machine Shop Revisions
- Met with Gregg Bennett to make modifications to our physical apparatus according to our initial testing from the previous day. 
# 2022-04-06 -- Load Cell
- Met with John to test load cell using our initial software code. Got the load cell to output force readings to our serial monitor in Arduino. 
- https://www.instructables.com/Arduino-Scale-With-5kg-Load-Cell-and-HX711-Amplifi/ -- Tried following this tutorial   
# 2022-04-11 -- Testing & Integration 
- Met with John to independently test push buttons, servo motors, and load cell working. Integrated all three components to work in conjunction with one another. 
- Ordered USB Host Shield to test card reader. 
- https://docs.arduino.cc/built-in-examples/digital/Button -- Tried following this tutorial
# 2022-04-12 -- Second Round PCBs Arrived 
- De-soldered parts from old PCB and began soldering and preliminary testing on second PCB.
- There were issues with power delivery as it was exceeding the intended 5V delivery, so we used a separate external blank PCB board with MOSFETs and capacitors to properly regulate voltage from the DC power supply. 
<p align="center">

</p>
<p align="center">
 
</p>
<p align = "center">
<strong> Voltage Regulator (top) Connected to PCB (bottom) </strong>
</p>

# 2022-04-15 -- Received New Continuous Servo Motor & QR Scanner Testing
- Met with John to test new continuous servo motor in conjunction with the load cell, non-continuous servo motor, and push buttons. 
- Tested out QR scanner. We had a lot of issues with the QR code being not read in as a valid code and figured out that we needed to use a static QR code, rather than a dynamic one. 
- https://docs.arduino.cc/tutorials/mkr-vidor-4000/VidorQrRecognition -- Tried following this tutorial
# 2022-04-16 -- Swap to MSR90 Card Reader
- We were struggling a lot with the MSR 123 card reader, as it was not even initializing as an HID device, so we switched to the MSR 90 card reader, and it was able to successfully read in UIN data from our iCards.
- Integrated the software side for each module and tested the machine as a whole. The software worked for dispensing as well as retrieving.
<p align = "center">


</p>
<p align = "center">
<strong> RETRIEVAL (left) AND DISPENSAL (right) </strong>
</p>

# 2022-04-17 -- PCB Debugging 
- Attempted to integrate PCB with our software, but our PCB was not working. 
- Probed all the components on our board, and found there was a huge voltage drop across components that were on the right side of the board. 
- Determined this voltage drop to be caused by a corroded SMD voltage regulator, which restricted current a lot.
  - Cause of corrosion was due to using water-soluble flux when desoldering from our original PCB
# 2022-04-22 -- Mock Demo
- Conducted our Mock Demo with our TA (Akshat). Tidied up final apparatus and got ready for final demo. 

# 2022-04-26 -- Final Demo 
- Present project in front of our TA (Akshat) and Professor Song. 
- Preparation for final presentation.

# 2022-05-03 -- Presentation
- Present in front of our TA (Akshat) and Professor Song.

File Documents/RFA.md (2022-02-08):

Team Members:

Ariocie Liang (arliang2), John Kim (jaehank2), Henry Guan (henryg3)

## PROBLEM

Good2Go (G2G) containers are used all throughout dining halls for individuals wanting to take their food to go. The program allows you to trade in an old container for a token, where that token can then be used to trade for a new container. This is a hassle for both parties that handle the entire process. It's very redundant and can be streamlined/improved with mechanical assistance.

## SOLUTION

Our solution involves a token/food container swapping machine that serves 2 main functions:

Have a G2G token, that upon deposit, returns a clean container
Accept a used container, returning a G2G token or a clean container
The goal here is to make the process semi-autonomous by removing 2 stages of interaction, as well as speeding up the entire process by doing so.

# SUBSYSTEMS

## Initial State:
The initial state of the machine will be waiting for user input for either an {old container} or a {token}, which is read by the microcontroller

## Display Screen and Buttons:

The display screen along with the button is used to guide the user into selecting one of the two options. The first selection is {old container} and {token} which is used to inform the machine what it’s supposed to expect from the user. In the case of the {token}, the machine will read from the card swipe. The next option that will be displayed is {new container} and {token} which occurs in the event the user returns an old container. Based on the input, the machine will return either a new container or update the token info from the swiped card.

## Sensors:

QR scanner to identify valid containers by reading the food container ID and a wifi module to send it over to the microcontroller. If it is an invalid ID, the machine returns to its initial state. Otherwise, the machine will dispense either a {new container} or generate a {token}
Scale to measure weight so that once it exceeds {container weight + constant}, the machine will not accept the container and will return to its initial state. If the weight is within the threshold, the machine will dispense either a {new container} or generate a {token}
Card Swipe is used to process digital coins instead of physical ones. Each card will hold information of the number of tokens and will get updated for every swipe. If a card swipe is read from the initial state, the machine will dispense a new container

## Microcontrollers:

Microcontroller will keep track of the state transitions and will also be responsible for activating different motors and reading data from the scale, token as well as the food container ID. From the initial state (old container, token), if the user inputs an old container, the microcontroller will take input from the scale and activate the motor to receive the returned old container, and then wait for further user input for {new container} or a {token}. Otherwise if the user selects a token, the microcontroller will process the token and activate the motors to dispense a new container.

## Motors:

Motors will be wired to a pair of arms near the opening of where the user can place an old container. It will be placed on the same surface as the scale (on the bottom of the old container) so that once the motors are activated, it lifts up and acts as the pushing mechanism to deposit the old containers.
A different set of motors wired to two arms (spaced for a single container) will also be used to dispense new containers. Only a single container will be preloaded in between the arms, with the rest being loaded behind this single container at an angle. Upon the activation of the motors, the first arm closest to the drop chute will open first, dispensing the container. That arm will then close, followed by the second arm opening, allowing one container through. That barrier will then close, completing the process of preloading another container that's ready to dispense. 

CRITERION FOR SUCCESS

User should be able to start the process by pressing a button, selecting whether they are depositing a valid token or a used G2G container.
When a valid token is deposited, the machine should dispense a clean container and reset. If token is invalid, return token and reset.
When a G2G container is deposited, the machine should check that the container is valid (has a valid bar code and is not over a set weight limit)
If the deposited container is overweight, the machine waits for the user to pick up the container, clear it out, and set it down again.
Else, it will ask the user to select either a token or a clean container to be dispensed.
the machine will then dispense selected object and reset.
In total the entire process should take a minute per person to complete!

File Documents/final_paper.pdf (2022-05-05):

# Good2Go Automated Token Exchanger (GATEr)

### Ariocie Liang (arliang2) Henry Guan (henryg3) John Kim (jaehank2)

### ECE 445 Final Report, Senior Design, Spring 2022 Team 38 TA: Akshatkumar Sanatbhai Sanghvi May 05, 2022

ii

## Abstract

This project aims to create a product that streamlines and automates a service called Good2Go that is prevalent in the U of I dining halls. The original service provides a container that a student can use to take food to go from the dining halls in exchange for a token or an old container. The design focuses on automating the process of exchanging tokens and containers rather than having a student find a dining hall employee to complete the process. In this report, the project’s design, requirements and verifications, and results are comprehensively detailed. Although there were small shortcomings and issues that affected the ideal final product, our team achieved a proof of concept design that provides a solution to the current problems of the Good2Go system, which is exposed to several security and labor issues.

iii

## Table of Contents

## 1. Introduction

### 1.1 Problem Statement

Since the pandemic began, more and more people have had to become isolated to avoid the spread of COVID-19. As a response to such measures, the U of I dining hall system implemented a token/container exchanging system named Good2Go (G2G) to allow students to take food from the dining halls. The system allows students to exchange an old container for a redeemable wooden token to then exchange for a new container [1]. The current process lacks a unified system across all U of I dining halls and relies heavily on human supervision and interaction. Furthermore, the intermediate process of having to receive a physical token first in order to exchange for a new container causes significant delay in the system when students can directly exchange a new container by returning an old one. The current system also proves to be a hassle for both parties involved in the process since it is too simple to have a single person be assigned to it, but occurs often and spontaneously enough to become bothersome.

### 1.2 Solution

To solve the above problem, we developed a machine that automates the process of exchanging tokens and containers. The machine is capable of storing digital tokens, removing any inconvenience caused by carrying a physical token such as concern for loss. The system not only allows an exchange between old containers and tokens but also a direct exchange between old containers and new containers. The goal of the machine is to transform the process into a semi-autonomous system by removing human to human interactions and also allowing users a choice to select between a digital token and a new container. This improves the efficiency, simplicity, and performance speed of the current G2G container system.

The machine activates upon a card swipe to strictly allow only U of I students for access using their iCards. A QR sensor and a load cell are used to detect validity of the containers using weight measurements and G2G QR code. The front of the machine has LED status messages to show user-friendly instructions as well as push buttons to take user input. Lastly the microcontroller and motors are used to process the internal state of the machine and execute the actions necessary to retrieve or dispense containers and digitally update a user’s token count. The sensors are the main replacement of the human to human interaction with the role of authenticating valid containers and tokens. The validity of each container is defined by its QR code as well as the weight to ensure minimal food waste within the G2G containers.

### 1.3 High Level Requirements

The three high level requirements below outline the successful functionality of the machine:

1. The system should deliver the entire process from receiving an old container or token to dispensing a new container in less than 15 seconds, assuming minimal delay in the user’s action.
2. The system should dispense exactly one new container at a time indefinitely without jamming and should never allow more than one container to be dispensed upon a single request

3. The system must correctly reject invalid G2G containers without QR codes or with weight that exceeds 7g compared to the base weight.

The first high level requirement ensured that the machine could handle a high number of users by leaving ample time to make their selection while minimizing delay to complete the exchange. The next high level requirement ensured that all exchanges were one-to-one; in other words, no user should ever accidentally receive more than one container or receive none due to a mechanical fault in the system. The final high level requirement ensured that fraudulent exchanges with invalid containers were rejected, and only fully validated containers could continue through the exchange process. All three requirements were met by the final design and will be further discussed in Section 2 of the paper.

### 1.4 Subsystem Overview

Figure 1 below outlines the four subsystems used in our machine. The power subsystem supplied 12V to the motors in the control subsystem, 3.3V for the LEDs and 5V to all other components including the microcontroller and sensor modules. The control subsystem had motors receiving different data signals from the main microcontroller to activate the two types of mechanical arms responsible for retrieval and dispensing system. The UI subsystem mainly handled reading user inputs from the push buttons and outputting LED status messages for instructions. Finally, the sensing subsystem was used as a method of validation for both the user and the container. The load cell and QR scanner were responsible for verifying the weight and the QR code of a G2G container while the card reader was placed to authenticate user information through iCards.

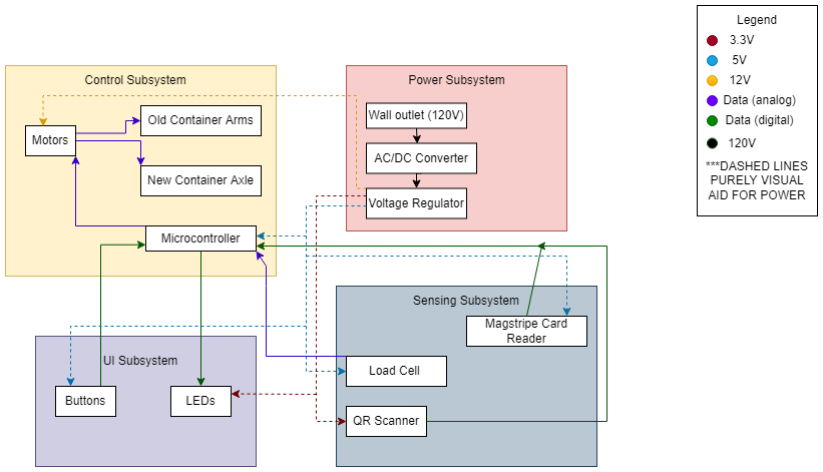
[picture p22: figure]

Figure 1. Block Diagram of the G2G Machine

## 2. Design

### 2.1 Design Procedure

With the current Good2Go system being only a service and not a product, the machine required complex design specifications accounting for different specs of each module. The scanning distance and field of view of the QR sensor required specific distance and tilt threshold from the containers while the load sensors and mechanical arms were placed in conjunction to parallelize the action of validating and retrieving returned containers. The base top-down view in Figure 2 also shows how returned containers are retrieved into an empty bin by the mechanical arms. The most intricate part of the mechanical design was the dispensing system, which required a mechanism to output exactly one container without any faulty behaviors such as physical jamming. This was done using a treadmill system powered by a continuous servo motor with an opening for exactly a single container height (1.25in) as shown in the bottom two diagrams of Figure 2.

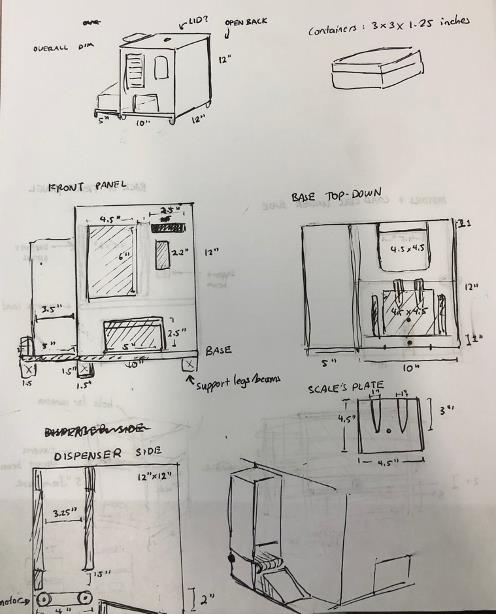
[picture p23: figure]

Figure 2: Design Specification of the G2G Machine

The design procedure also consisted of assigning another layer of state transition to the current G2G system to allow a direct exchange between old containers and new containers. Figure 3 below illustrates the finite state machine of the logic flow in which the initial state corresponds to the machine’s idle state waiting for a card swipe.

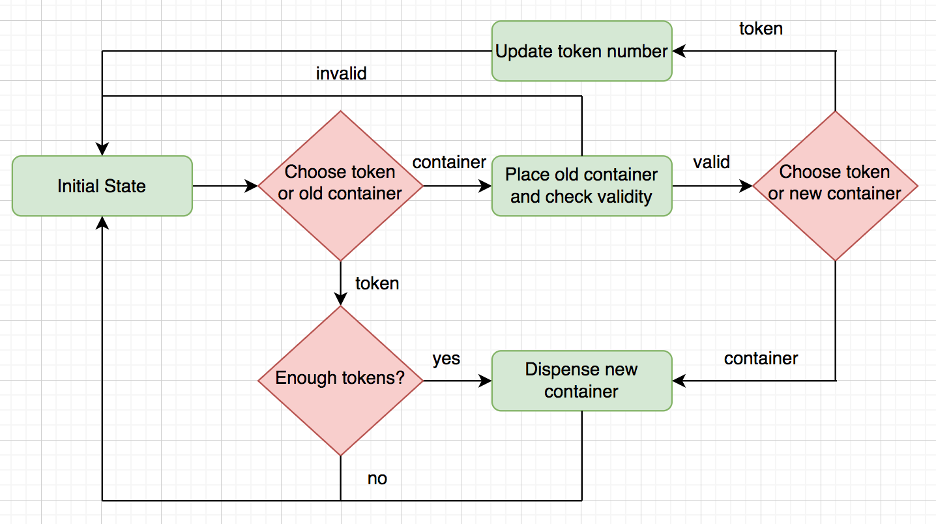
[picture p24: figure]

Figure 3: FSM of the G2G machine

### 2.1.1 UI Subsystem

The main design consideration for the user interface (UI) subsystem was between an LCD (liquid crystal display) screen and a multiplexer LED (light-emitting diode) status. An LCD screen had the advantage of displaying custom messages and easy to use libraries that had built in functions for an I2C or serial communication. However, the G2G machine had a similar functionality to that of a normal vending machine, and thus had little to no information to display to users. Most of the identity verification that happened under the hood was abstracted away and revealing sensitive information such as the student’s UIN (university ID number) could have created security issues. Additionally, the project schematic used three microcontrollers (1 ATmega328P and 2 ATtiny85s) for managing the control logic with a limited number of digital pins, but even a relatively small 2x16 LCD screen required at most 14 pin connections [2]. An I2C adaptor could be used to cut down on the number of digital pins but incurred additional cost and was not included in the original PCB modification.

Thus, the final design decision was to use LED status messages, which also aided in visualizing the state transitions shown in Figure 3. Figure 4.1 below illustrates the schematic for the two push buttons as well as the LEDs that are connected to an 8-to-1 demux. The two push button pins labeled B0 and B1 correspond to a selection of token and container respectively, and are connected back to pin 23 and 24 of the ATmega. Each output of the demux made a serial connection with a 220Ω resistor before making a final connection with the positive anode of the LEDs to prevent excess current from burning any components [3].

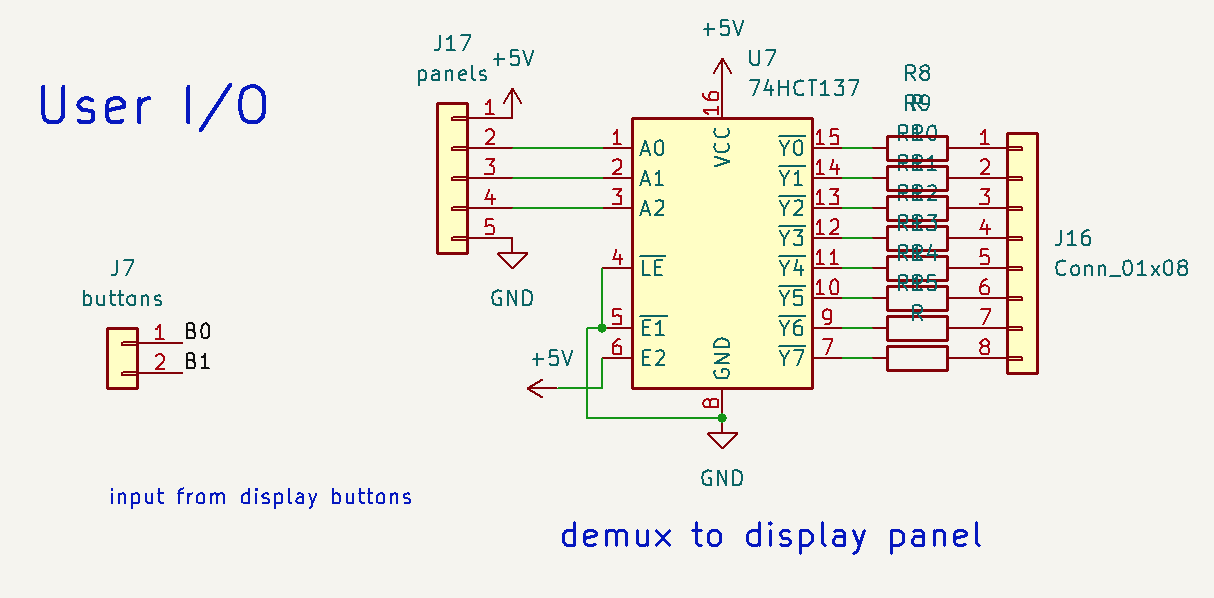
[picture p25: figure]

Figure 4.1: UI Schematic for Display and Buttons

The three select pins A0, A1, A2 controlled which output pin from Y0 to Y7 to set as LOW as shown in Figure 4.2 [4]. The HCT138 demux used was active low with NOR gates connected to each of the output gates. Thus, the G2G machine with LED status messages initially had all lights turned on until a state transition occurred to represent the current stage of the exchange.


Figure 4.2: Function Table of 3-to-8 Demultiplexer (L = Low, H = High)

### 2.1.2 Sensing Subsystem

The sensing subsystem had a total of three different modules with QR scanner and load cell being used for the validation process of G2G containers while a magnetic card swipe was used for identity verification of the user. A popular choice for digital identification was using a RFID (radio-frequency identification) tag as it already had heavily detailed libraries compatible with Arduino code [5]. However, the G2G system was aimed to provide service exclusively to U of I students using their iCards. Thus, instead of introducing another layer of security ID, modifying a magnetic card reader suitable to read actual iCards was the main reason for such design choice.


Figure 5.1: Sensor Schematic for Magnetic Card Swipe

The left component in Figure 5.1 shows the USB port of the magnetic card swipe with D+ and D- pins used to transfer data between the host (microcontroller) and the device (card reader). The card swipe had its own smaller microcontroller unit shown on the right of Figure 5.1 that connected back to the main microcontroller. The ATtiny was responsible for reading the raw card data while the main microcontroller ATmega decided on the validity of the user based on the input from the ATtiny.

In addition to the USB card reader, the G2G machine required a mechanism to detect the amount of food waste within the returned containers. Using a typical scale had two major issues as it was too big to fit in the downscaled machine and also did not have the accuracy to measure extremely light plastic containers. A load cell offered a solution to both of these problems as a small transducer to convert force into measurable electrical output. Although it required a calibration process for accurate measurements, using an amplifier allowed a digital reading of small weights. The specific type of the load cell used was a strain gauge bending beam load cell, which represented the load of an object placed with a degree of voltage change [6]. The bending beam load cells offered low-profile construction for limited space and were flexible at relatively low forces, making them suitable for lower capacity applications such as the G2G containers [7].


Figure 5.2: Sensor Schematic for Load Cell

The initial four wires labeled E+, E-, S-, S+ on the very left of Figure 5.2 were taken from the load cell and connected to the HX711 amplifier to amplify the output signal. The two outputs of HX711 labeled as PD_SCK and DOUT were then connected to SK and DT respectively, which stands for serial clock and data out [8]. The final output of the load cell was fed back to the main microcontroller at pin 15 with digital reading of the weight. The load cell was used to reject any containers that weighed more than 10g with the base weight of the G2G container being approximately 3g, allowing a maximum 7g of food waste.

Lastly, a QR scanner module was used to verify the object placed on the load cell as a valid G2G container through the use of QR codes. The main difference between QR codes and barcodes was the amount of information that could be stored as QR codes had another physical dimension from which data could be written and scanned [9]. The initial design decision was to use a barcode scanner as the machine required nothing more than a static ID verification for the G2G containers. However, barcodes required a linear scan and were thus susceptible to errors based on different orientations and placements. To allow more flexibility and account for possible human errors, QR scanner was used to offer a more stable solution.


Figure 5.3: Sensor Schematic for QR scanner

The QR scanner module utilized a serial port for an UART communication with an ATtiny microcontroller using the Rx (receive) and Tx (transmit) pins as shown in Figure 5.3. The Rx pin of the QR was used to receive any data from the microcontroller, which was mostly composed of UART scan commands to change some of the default settings of the module. The Tx pin was used to send any read QR codes to the Rx pin of the microcontroller to determine a valid G2G container.

### 2.1.3 Control Subsystem

Once all the validation was complete by the sensing subsystem, the main microcontroller was responsible for sending any appropriate data to the motors, which were responsible for safe and accurate execution of dispensing and retrieving G2G containers.

The final product incorporated a non-continuous servo motor for the retrieval system and a continuous servo motor for the dispensing system. The two main reasons for using a servo motor instead of a stepper motor was because of the closed loop control it provided along with an increased torque at high speed. The stepper motor had an advantage of providing high torque at low speed and was easy to use [10]. However, the design of the control subsystem had significant weight placed on the motors for not only the mechanical arms attached to the shaft but also the G2G containers placed on top of the treadmill. This also induced frictional force that further cut down on the natural torque provided by the motor, making servo motors the ideal choice for the machine.


Figure 6: Control Schematic for Servo Motors

The two servo motors received commands from the main microcontroller regarding position data and pulse signals from pin 27 and 28 with pins 25 and 26 being unused. The non-continuous motor would turn its shaft based on the desired angular position sent from the ATmega while the continuous motor received information on both the direction of rotation as well as the RPM.

### 2.1.4 Power Subsystem

The machine was intended to draw power from a wall outlet, and thus required an AC/DC converter as a component. The 12V output of the converter was designed to feed into the voltage regulator as shown in Figure 7 to output a steady 5V supply to the rest of the modules.


Figure 7: Power Schematic for Voltage Regulator

### 2.2 Design Details

### 2.2.1 UI Subsystem

The two push buttons used for the machine operated in a maintained-contact mode that stayed on upon a press and turned off when pressed again. Thus, the change in the status of the push buttons made by the users were measured by the difference in the ON and OFF states rather than keeping track of when exactly the press was detected. This allowed multiple other processes with higher priority such as the USB task and UART serial communication to run while saving the initial state of the push button to detect a change when needed.

One small modification made from the original PCB design was the addition of a pull-down 10KΩ resistor for a serial connection with the push buttons. This was done as a fix for an incorrect digital reading of the button status as shown in the serial monitor outlined in Figure 8. The left side of Figure 8 shows the correct readings of the push button that switched state from OFF (0) to ON (1) upon a button press. However, the button status momentarily reflected an ON state when the push button remained unpressed as shown on the right side of Figure 8.


Figure 8: Serial Monitor Output of Button Status

This was due to a floating input in the microcontroller pin with no defined logic state, leaving the appearance of a button press that falsely triggered the circuit [11]. The use of a pull-down resistor forced the behavior of the push button to have a digital reading of LOW (0) when there was no connection between the two legs of the button while a digital reading of HIGH (1) when the connection was made from a press.

The LED status messages were used to represent the six different states of the FSM, and required writing to the A0, A1, and A2 digital pins of the demux to set the three select bits. The Y0 output was used to represent the initial state of the machine waiting for a card swipe, followed by Y1 to Y5 representing the select, retrieval, dispense, update, and invalid states respectively.

### 2.2.2 Sensing Subsystem

As one of the most complex parts of the project, the magnetic card reader required interfacing with a HID (human interface device) Keyboard as card swipes imitated the same interrupt behavior as that of a keyboard. Each card swipe responded to both key-down and key-up interrupts along with any special character key presses such as SHIFT and CAPS. The left image of Figure 9 below shows the raw data output read from the keyboard interrupts of a card swipe while the right image shows the output after modification in the driver code. The data parsing allowed each iCard swipe to identify as a university card and to recognize the UIN (university identification number) of the user.


Figure 9: Output Data of Magnetic Card Swipe

The important parts of the load cell design consisted of determining the load cell resolution as well as the minimum weight measurable. The graph in Figure 10 expresses the relationship between the FSO (full scale output) and the amount of load on the load cell. Calculating such minimal weight was critical as the G2G containers needed accurate measurements for detecting small amounts of food waste. Equation (1) takes the maximum load to assess the output voltage (display’s input sensitivity) required to give a readout of the smallest measurable weight [12].

max measuring range
number of divisons × max load =

output voltage
excitation voltage | (1)

Using the specification of the load cell from the data sheet in Equation (1) gave a final input sensitivity of 0.72µV, an upper bound of the output voltage to read a weight of 0.3g.

output voltage =

1500g × 3.6mV
5000 × 1500g
= 0.72 μV | (2)


Figure 10: Relationship Graph Between Load and Load Cell Signal

The QR scanner had a built in image recognition algorithm and most of the work needed was changing the default behaviors of the module that were incompatible with the intended design of the machine. The module’s baud rate had to be changed from 9600 to 115200 to be synchronized with the card reader and the scanning mode had to be changed to run continuously to not enter a sleep mode when inactive for a period of time. Sending specific UART scan commands in the datasheet allowed the QR scanner to enter a continuous scanning mode by setting bit0 to 1 at address 0x02 [13].

### 2.2.3 Control Subsystem

The two servo motors used for the retrieval and dispensing system operated in different modes. The non-continuous motor for retrieving received position data from the microcontroller, going from 0° to 120° with a delay of 10ms between each angle. This was done to minimize any safety issues as the retrieval motor was placed near the bin exposed to user contact.

The continuous motor for dispensing went through precise calibration as the functionality required a specific pulse of 1.5ms to stop the motor from rotating. Even a small drift would cause significant rotation over time, resulting in possible dispensing of new containers. The adjustment was made using a potentiometer with PWM (pulse width modulation) to send a 1.5ms pulse for the stopping condition of the servo motor [14].

### 2.2.4 Power Subsystem

The power subsystem plugged into a standard US wall outlet that could output 12V from 120VAC and could convert the voltage to the adequate DC voltage required by the other components in each subsystem. The converter had a built-in 10:1 transformer to step down from 120V to 12V, which was fed as an input to the voltage regulator to supply a steady 5V. The two stepper motors drew a lot of current and thus required a separate power supply, which was taken from a battery pack of 5V.

## 3. Verification

### 3.1 UI Subsystem

The requirement for the UI Subsystem was to correctly keep track of a user’s token count within the magstripe card (Appendix A, Table 4.1). Another requirement was to have the system correctly keep track of any user input through the push buttons (Appendix A, Table 4.2). To verify both of these requirements, we exchanged a single container for a token in the first iteration, and used the token to exchange for a new container in the next iteration to verify a successful token update. In the final iteration, we attempted to spend a non-existent token to check the validation process of the user’s token count, making sure that no new container was dispensed.

### 3.4 Sensing Subsystem

The requirement for the sensing subsystem was to have a successful completion of a QR scan and accurate weight measurement of the G2G containers within a 1g tolerance (Appendix A, Table 7.1). To verify the stated requirement, we checked for a valid QR code scan from the serial monitor and made comparisons of the load cell measure against a known container weight. The other requirement was to have the system correctly execute retrieval and dispensal for valid G2G containers (Appendix A, Table 7.2). This was verified by checking if the system rejected containers that were overweight (> 10g) or had an invalid or non-existent QR code while continuing the exchange process for all valid containers.

### 3.3 Control Subsystem

The requirement for the control subsystem was to have the G2G machine complete the entire exchange process within 15 seconds from start to finish, assuming minimal delay on the user’s side (Appendix A, Table 6.1). To verify the stated requirement, we conducted several repetitions of completing an exchange, timing it from start to finish, ensuring that the maximum total time taken did not exceed 15 seconds. The other requirement was to have the machine dispense exactly one new container upon a dispensal request without any mechanical issues (Appendix A, Table 6.2). Similarly, this was also verified by conducting several repetitions of completing an exchange, ensuring no skew or drift in the motors were causing the machine to dispense a container more than once.

### 3.2 Power Subsystem

The power subsystem required each component to be powered in accordance within a 5% variance of the rated voltage outlined in Figure 1. We used a multimeter to check the connection between our 12V supplied power, ensuring that it delivered power to each voltage regulator first. The rest of the components were probed to check for a steady voltage supply of 5V with a maximum variance of 5% of the rated voltages (Appendix A, Table 5).

## 4. Costs & Schedule

### 4.1 Costs

Table 1: Cost Breakdown of Each Component

Part | Part Name | Price Per Unit | Quantity | Price
Push Button | GSW-21 | $5.18 | 2 | $10.36
White LED | 57P7143 | $0.47 | 6 | $2.82
Red LED | HLMP1340 | $0.39 | 1 | $0.39
Servo Motor | HS-311 | $13.54 | 1 | $13.54
Servo Motor | FS5103R | $11.95 | 1 | $11.95
Load Cell Sensor | TAL221 | $9.95 | 1 | $9.95
QR Scanner | SKU 14810 | $49.99 | 1 | $49.99
Microcontroller | X000048 | $7.20 | 1 | $7.20
MSR90 Magstripe Card Reader | MSR90 | $20.23 | 1 | $20.23
Total Cost: | | | | $126.43

The labor costs for the team members were calculated from the 2020-2021 annual Illini Success Report [15]. Ariocie is an Electrical Engineering major with an average salary of $80,296. John and Henry are Computer Engineering majors with an average salary of $105,352. A 10 hours per week work for a total of nine weeks came out to be 90 hours of work per engineer. Thus, the total labor costs for an Electrical Engineering major was 1 engineer × 2.5 × $38.60/hr × 90 hours = $8,685 and for two Computer Engineering majors was 2 engineers × 2.5 × $50.65/hr × 90 hours = $22,792.50.

The current labor rate for machine shop workers in the state of Illinois is $33,000/year [16]. Skee Aldrich and Gregg Bennett worked 13 hours during the semester for this project. Thus, the total labor costs for two machine shop workers came out to be 2 workers × 2.5 × $15.87/hr × 13 hours = $1031.55. The total labor cost across the machine shop workers and engineers was $32,509.05.

Table 2: Labor Cost Breakdown

Name | John Kim | Ariocie Liang | Henry Guan | Machine Shop
Rate | $50.65 | $38.60 | $50.65 | $15.87
Hours Worked | 90 | 90 | 90 | 13

Labor Support Rate | $75.98 | $57.90 | $75.98 | $23.81
Total Labor Costs | $11,396.25 | $8,685.00 | $11,396.25 | $1,031.55

### 4.2 Schedule

Table 3: Weekly Schedule of Each Team Member

Week | John Kim | Ariocie Liang | Henry Guan
2/21 | Complete Design Document. | Complete Design Document. Decide on parts to use. | Complete Design Document. Decide on parts to use.
2/28 | Complete Design Review. Work on PCB for approval for first round orders. | Complete Design Review. Work on PCB for approval for first round orders. | Complete Design Review. Work on PCB for approval for first round orders.
3/7 | Work on software code. | Solder and mount components to the PCB. Test PCB | Solder and mount components to the PCB. Test PCB
3/14 | Spring Break | Spring Break | Spring Break
3/21 | Continue working on software code. | Revise PCB for second round orders. | Work with John on software code.
3/28 | Complete Individual Progress Report. | Complete Individual Progress Report. | Complete Individual Progress Report.
4/4 | Address software issues with the G2G system. | Solder and mount components to the second PCB. Test PCB. | Solder and mount components to the second PCB. Test PCB.
4/11 | Complete software code. Unify system for final testing. | Test additional hardware and address issues. Unify system for final testing. | Work with John on software code. Unify system for final testing.
4/18 | Mock Demo. Begin final demo preparation. | Mock Demo. Begin final demo preparation. | Mock Demo. Begin final demo preparation.
4/25 | Final Demo. Work on presentation and final paper. | Final Demo. Work on presentation and final paper. | Final Demo. Work on presentation and final paper.
5/2 | Final Presentation and Final Paper | Final Presentation and Final Paper | Final Presentation and Final Paper

## 5. Conclusion

### 5.1 Accomplishments and Uncertainties

The final product of the G2G machine was able to meet all three of the high level requirements stated in Section 1.3 of the paper. The project provided a proof of concept design that provides several beneficial effects on the labor cost and user satisfaction of the G2G take-out system by improving efficiency and eliminating any human delay in the current system. The final product allows direct exchange between old containers and new containers as well as digitizing all user related information in the iCard. This further adds to the practicality of the machine, allowing current U of I students an easy access without any additional purchases of security IDs.

Despite having the full functionality achieved, the project was not able to meet some of the requirements for the individual subsystem specifications. The power subsystem required an AC/DC converter, but the product itself did not arrive on time to incorporate in the final design. The issue was partially remedied by having a voltage regulator that fulfilled half of the power subsystem requirements. Additionally, the full PCB schematic was not incorporated into the project as several critical components such as the USB cable and specific capacitors were missing due to miscommunication within the team.

### 5.2 Ethical Considerations

Throughout the duration of the project, we kept ethics and safety a top priority. In Code I1 of the IEEE Code of Ethics, it states that we must “hold paramount the safety, health, and welfare of the public” [17]. The code was closely applied to the initial goals of the project as it required creating a mechanism of retrieval and dispensing that was free of mechanical faults to minimize the possibility of physical injury.

Additionally, the automation of the current G2G container exchange system could have introduced a few security issues. With the aim of removing any human supervision, the sensor modules were required to achieve complete and accurate functionality. To avoid any possible malicious attempt to steal or damage the components of the machine, we ensured that all parts of our device were concealed and abstracted away from the user while running thorough testing of any mechanical faults. With how digitized the world is becoming, exposure of even the smallest personal information could lead to detrimental consequences. Thus, we also ensured that all user information including the UIN and digital tokens were confidential and protected. This was in alignment with codes 1.6 and 1.7 in the ACM Code of Ethics, which states that we must “respect privacy” and “honor confidentiality”, respectively [18]. We vow to uphold any user’s personal information and privacy by keeping all data internally protected.

Lastly, there were also safety concerns that applied to the development of our project when working inside the lab. In accordance with federal and state regulations as well as the campus lab policies, we made sure not to work alone in the lab, avoid bringing food or drinks, not remove any test equipment from the lab station, and clean up after ourselves so that the workspace was hazard-free [10].

### 5.3 Future Work

For the current G2G machine, it uses on-chip memory to store user information such as the token number, and thus has a limited number of 10,000 write cycles. Although the number may most likely be enough to keep track of all the current token updates, having a relational database using SQL could make the system more durable. Additionally, the growth of the G2G system may introduce different sizes and types of containers, and may require a strict deadline for users to return what they borrowed. These extra pieces of information can easily be added if the system utilizes a database to maintain the structure, also allowing greater scalability to be used in all dining halls.

Lastly, the use of a display screen could enhance user experience with on screen instructions and also present several selections rather than just two choices between tokens and containers. Although the LED status messages were more suitable for the current state of the machine, digital screens would allow greater flexibility to any potential design changes to the product.

## References

[1] University Housing, “Good2Go carry-out program,” University Housing. [Online]. Available: https://housing.illinois.edu/Dining/Locations/Good2Go-Carry-Out-Program. [Accessed: 30-Apr-2022].
[2] T. A. Team, “Liquid Crystal Displays (LCD) with Arduino: Arduino documentation,”
Arduino Documentation | Arduino Documentation. [Online]. Available:
https://docs.arduino.cc/learn/electronics/lcd-displays. [Accessed: 03-May-2022].
[3] “Resistors for led circuits: Resistor applications: Resistor Guide,” EEPower. [Online]. Available: https://eepower.com/resistor-guide/resistor-applications/resistor-for-led/#. [Accessed: 03-May-2022].
[4] Datasheet 74HC/HCT138. [Online]. Available: https://www.digchip.com/datasheets/parts/datasheet/364/74HC_HCT138-pdf.php. [Accessed: 03-May-2022].
[5] “RFID scanner - full tutorial,” Arduino Project Hub. [Online]. Available: https://create.arduino.cc/projecthub/shubamtayal/rfid-scanner-full-tutorial-6518db. [Accessed: 03-May-2022].
[6] O. Engineering, “Load Cells & Force sensors,” https://www.omega.com/en-us/, 29-Apr-2022. [Online]. Available: https://www.omega.com/en-us/resources/load-cells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,ga uge%20when%20it%20undergoes%20deformation. [Accessed: 03-May-2022].
[7] “How does a bending beam load cell work?: Working Principle,” HBM, 09-Sep-2019. [Online]. Available: https://www.hbm.com/en/2973/how-does-a-bending-beam-load-cell-work/. [Accessed: 03-May-2022].
[8] “Tal221 miniature load cell - cdn.sparkfun.com.” [Online]. Available: https://cdn.sparkfun.com/assets/9/9/a/f/3/TAL221.pdf. [Accessed: 02-May-2022].
[9] “QR code vs Barcode: Why the difference matters,” Paysley Blog, 10-Feb-2022. [Online]. Available: https://paysley.com/blog/qr-code-vs-barcode/. [Accessed: 03-May-2022].
[10] “Stepper vs Servo,” Tutorial: Stepper vs Servo. [Online]. Available: https://www.amci.com/industrial-automation-resources/plc-automation-tutorials/stepper-vs-servo/. [Accessed: 03-May-2022].
[11] D. Lancaster, “Do push buttons need resistors?,” Electronic Guidebook, 08-Jan-2021. [Online]. Available: https://electronicguidebook.com/do-push-buttons-need-resistors/. [Accessed: 03-May-2022].
[12] “What is the lowest weight a load cell can measure?,” Tacuna Systems, 31-Mar-2022. [Online]. Available: https://tacunasystems.com/knowledge-base/load-cell-lowest-weight/. [Accessed: 03-May-2022].

[13] Waveshare Barcode Scanner Module. [Online]. Available: https://www.waveshare.com/w/upload/archive/3/3c/20180623102926%21Barcode_Scanner_Module_User_Manual_EN.pdf. [Accessed: 02-May-2022].
[14] Adafruit, Continuous Rotation Servo - FeeTech FS5103R. [Online]. Available: https://media.digikey.com/pdf/data%20sheets/adafruit%20pdfs/154_web.pdf. [Accessed: 02-May-2022].
[15] “Part of University of Illinois,” Box. [Online]. Available: https://uofi.app.box.com/s/aoply09y5kf6i36es8v3bl758n2lfl08. [Accessed: 02-May-2022].
[16] Zippia, “Average Machine Shop Worker Salary in Illinois,” AVERAGE MACHINE SHOP WORKER SALARY. [Online]. Available: https://www.zippia.com/machine-shop-worker-jobs/salary/. [Accessed: 02-May-2022].
[17] “IEEE code of Ethics,” IEEE. [Online]. Available: https://www.ieee.org/about/corporate/governance/p7-8.html. [Accessed: 02-May-2022].
[18] “ACM Code of Ethics,” Code of Ethics. [Online]. Available: https://www.acm.org/code-of-ethics. [Accessed: 02-May-2022].

## Appendix A - Requirement and Verification Tables with Results

Table 4: UI Subsystem R&V Table

Requirement | Verification | Verification Status
1. Correctly keep track of a user’s token count. | 1. Test the system to see if it can detect if the user has invalid tokens, as well as if the system is able to store a token and use said token. | Yes, refer to Figure 11, Appendix B.
2. Correctly keep track of user input. | 1. Test to see if the system executes the intended action on the push button the user selects. | Yes, refer to Figure 12, Appendix B.

Table 5: Power Subsystem R&V Table

Requirement | Verification | Verification Status
1. Power all components in accordance with their rated voltage within 5% variance. | 1. Use a multimeter for each component, ensuring that each component’s measured voltage is within 5% variance of its’ rated voltage | Yes, refer to Table 8, Appendix B.

Table 6: Control Subsystem R&V Table

Requirement | Verification | Verification Status
1. Machine should complete an exchange within 15 seconds, from start to finish. | 1. Utilize repetitive tests and time how long it takes to complete an exchange. | Yes.
2. Dispensing exactly one container upon receiving a dispensal request without any mechanical issues. | 1. Repetitively complete exchanges for new containers, and check to see if exactly one container is dispensed. | Yes.

Table 7: Sensing Subsystem R&V Table

Requirement | Verification | Verification Status
1. Successful completion of a QR scan and accurate weight measurement of the G2G | 1. Check to see if QR enables a correct scan and that the load cell accurately measures the known mass of a container. | Yes, refer to Figure 14, Appendix B.

containers within a 1g tolerance.

2. Correctly execute retrieval and dispensal only for valid G2G containers | 1. Reject containers that are overweight or have an invalid/no QR code, while executing retrieval or dispensal for valid containers. | Yes, refer to Figure 15.

## Appendix B – Verification Outputs


Figure 11: Serial Monitor Output of Invalid Token Use


Figure 12: Serial Monitor Output of Token Usage

Component | Measured Voltage Rating
ATMega328P | 4.997V
ATTiny85 | 4.996V
Load Cell | 4.988V
Push Buttons | 4.928V
Servo Motors | 4.946V
Card Reader | 4.898V
QR Scanner | 3.295V
LEDs | 3.323V

Table 8: Multimeter Readings of PCB Components


Figure 14: Serial Monitor Output of Valid Container Detection


Figure 15: Serial Monitor Output of Invalid Container Detection

## Appendix C – PCB Layout


Figure 16: PCB Layout of the G2G Machine

## Appendix D – PCB Schematic


Figure 17: PCB Schematic of the G2G Machine

## Appendix E – Software Code

1. // for card reader - HID boot keyboard
2. #include <hidboot.h>
3. #include <usbhub.h>
4.
5. // Satisfy the IDE, which needs to see the include statment in the ino too.
6. #ifdef dobogusinclude
7. #include <spi4teensy3.h>
8. #endif
9. #include <SPI.h>
10.
11. #include "HX711.h"
12. #include <Servo.h>
13. #include <SoftwareSerial.h>
14. #include <EEPROM.h>
15. // #include <LiquidCrystal.h> 16.
17. // loadcell
18. #define calibration_factor -7050.0
19. #define DOUT 4
20. #define CLK 3
21.
22. HX711 scale;
23.
24. Servo servoD; // continuous servo for dispensing
25. Servo servoR; // non-continuous servo for retrieving 26.
27. SoftwareSerial qr(0, 1); // Rx, Tx
28.
29. // LCD Display
30. //int contrast = 60;
31. //const int v0 = A2, rs = 7, en = 8, d4 = 9, d5 = 10, d6 = 11, d7 = 12;
32. //LiquidCrystal lcd(rs, en, d4, d5, d6, d7);
33.
34.
35. String qr1 = "3213";
36. String qr2 = "3214";
37. String qr3 = "3212";
38.
39. const int buttonL = 8;
40. const int buttonR = 7; 41.
42. const int servoD_pin = 2;
43. const int servoR_pin = 6;

44.
45. const unsigned long timeout = 10000; // timeout value for QR set to 2 seconds 46.
47. int a0 = A0;
48. int a1 = A1;
49. int a2 = A2;
50.
51. int pos = 0;
52. int num_tokens = 2;
53. bool card_valid = false;
54. bool start = false;
55.
56. // card reader
57. String s = "";
58. bool card_read = false;
59. bool company = false;
60. bool unused = false;
61. bool uin = false;
62.
63. String John = "667474863"; 64.
65. struct student {
66. String netID;
67. int addr;
68. int tokenNum;
69. };
70.
71. student jaehank2;
72. student henryg3;
73. student* studentList[2] = {&jaehank2, &henryg3};
74. int idx = 0;
75.
76. class KbdRptParser : public KeyboardReportParser
77. {
78. void PrintKey(uint8_t mod, uint8_t key);
79.
80. protected:
81. void OnControlKeysChanged(uint8_t before, uint8_t after); 82.
83. void OnKeyDown (uint8_t mod, uint8_t key);
84. void OnKeyUp (uint8_t mod, uint8_t key);
85. void OnKeyPressed(uint8_t key);
86. };
87.
88. void KbdRptParser::PrintKey(uint8_t m, uint8_t key)
89. {

90. return;
91. };
92.
93. void KbdRptParser::OnKeyDown(uint8_t mod, uint8_t key)
94. {
95. uint8_t c = OemToAscii(mod, key);
96.
97. if (c)
98. OnKeyPressed(c);
99. }
100.
101. void KbdRptParser::OnControlKeysChanged(uint8_t before, uint8_t after) { 102.
103. return;
104.
105. }
106.
107. void KbdRptParser::OnKeyUp(uint8_t mod, uint8_t key)
108. {
109. return;
110. }
111.
112. void KbdRptParser::OnKeyPressed(uint8_t key)
113. {
114. s += ((char)key);
115. if (card_read == true && s.length() == 17){
116. Serial.println();
117. s = "";
118. card_read = false;
119. company = false;
120. unused = false;
121. uin = false;
122. return;
123. }
124. else if (company == false && s.length() == 19){
125. // Serial.println(s);
126. s = "";
127. company = true;
128. }
129. else if (company == true && s.length() == 21){
130. Serial.println(s);
131. s = "";
132. unused = true;
133. }
134. else if (s.length() == 14 && unused == true && card_read == false){
135. s = "";

136. uin = true;
137. }
138. else if (s.length() == 9 && uin == true && card_read == false){
139. Serial.print("UIN: ");
140. Serial.println(s);
141. if (s == jaehank2.netID){
142. idx = 0;
143. card_valid = true;
144. }
145. else if (s == henryg3.netID){
146. idx = 1;
147. card_valid = true;
148. }
149. else {
150. card_valid = false;
151. }
152. card_read = true;
153. s = "";
154. }
155. };
156.
157. USB | Usb;
158. //USBHub | Hub(&Usb);
159. HIDBoot<USB_HID_PROTOCOL_KEYBOARD> HidKeyboard(&Usb); 160.
161. KbdRptParser Prs;
162.
163. void setup() {
164. // put your setup code here, to run once:
165. Serial.begin(115200);
166. #if !defined(__MIPSEL__)
167. while (!Serial); // Wait for serial port to connect - used on Leonardo, Teensy and other boards with built-in USB CDC serial connection
168. #endif
169. qr.begin(115200);
170. Serial.println("Start");
171. if (Usb.Init() == -1){
172. Serial.println("OSC did not start.");
173. }
174. delay( 200 );
175. HidKeyboard.SetReportParser(0, &Prs);
176. // initialize student info
177. jaehank2.netID = "667474863";
178. jaehank2.addr = 0;
179. jaehank2.tokenNum = EEPROM.read(jaehank2.addr); 180.

181. henryg3.netID = "659439620";
182. henryg3.addr = 1;
183. henryg3.tokenNum = EEPROM.read(henryg3.addr); 184.
185. // initialize push buttons
186. pinMode(buttonL, INPUT);
187. pinMode(buttonR, INPUT);
188. // have all LEDs on
189. setLED(255, 255, 255);
190. // initialize non-continuous servo motor
191. servoR.write(0);
192. servoR.attach(servoR_pin);
193. servoR.write(0);
194. // initialize scale
195. scale.begin(DOUT, CLK);
196. scale.set_scale(calibration_factor);
197. scale.tare(); // Assuming there is no weight on the scale at start up, reset the scale to 0 198.
199. }
200.
201. void loop() {
202. // put your main code here, to run repeatedly: 203.
204. // save initial button status
205. int b1 = digitalRead(buttonL);
206. int b2 = digitalRead(buttonR); 207.
208. // Serial.println(b1);
209. // Serial.println(b2);
210. Usb.Task();
211.
212. start = true;
213.
214. if (card_valid == true){
215. Serial.println("card successfully read");
216. }
217.
218. // TODO: set LED status for IDLE/init - Y0
219. setLED(0, 0, 0);
220.
221. while (card_valid == true){
222. // TODO: set LED status for SELECT DEPOSIT - Y1
223. setLED(255, 0, 0);
224.
225. if (start == true){
226. start = false;

227. Serial.println();
228. Serial.println();
229. studentList[idx]->tokenNum = EEPROM.read(studentList[idx]->addr); 230.
231. Serial.print("your current token num: ");
232. Serial.println(studentList[idx]->tokenNum);
233. Serial.println("Select Deposit option");
234. }
235.
236. // get number of tokens for the user
237. // check pushbutton for using token
238. if (b1 != digitalRead(buttonL)){
239. Serial.println("Chose token");
240. card_valid = false;
241. // if not enough tokens, exit
242. if (studentList[idx]->tokenNum <= 0){
243. Serial.println("invalud num of tokens");
244. // TODO: set LED status for invalid tokens - Y5
245. setLED(255, 0, 255);
246. delay(2000);
247.
248. break;
249. }
250. // else update token and dispense
251. setLED(0, 0, 255); // updated - Y4
252. delay(2000);
253. studentList[idx]->tokenNum -= 1;
254. EEPROM.write(studentList[idx]->addr, studentList[idx]->tokenNum); 255.
256. Serial.print("your updated token num: ");
257. Serial.println(studentList[idx]->tokenNum);
258. // TODO: set LED status for dispense - Y3
259. setLED(255, 255, 0);
260.
261. dispense();
262. break;
263. }
264.
265. // check pushbutton for returning old container
266. if (b2 != digitalRead(buttonR)){
267. setLED(255, 255, 255); // Y7
268. Serial.println("Chose container: put container and scan");
269. card_valid = false;
270. bool qrValid = QRcheck();
271. Serial.println(qrValid);
272. float weight = scale.get_units(5);

273. Serial.print("weight: ");
274. Serial.println(weight);
275.
276. if (weight <= 5.0 && qrValid == true){
277. // TODO: set LED status for retrieving - Y2
278. setLED(0, 255, 0);
279.
280. retrieve();
281. // | b1 = digitalRead(buttonL);
282. // | b2 = digitalRead(buttonR);
283. // TODO: set LED status for SELECT DISPENSE - Y1
284. setLED(255, 0, 0);
285.
286. Serial.println("SELECT dispense option");
287.
288. // spin until button pressed
289. while (b1 == digitalRead(buttonL) && b2 != digitalRead(buttonR)); 290.
291. // if user pressed token for dispense
292. if (b1 != digitalRead(buttonL)){
293. studentList[idx]->tokenNum += 1;
294. EEPROM.write(studentList[idx]->addr, studentList[idx]->tokenNum);
295. Serial.print("your updated token num: ");
296. Serial.println(studentList[idx]->tokenNum);
297. // TODO: set LED status for token updated - Y4
298. setLED(0, 0, 255);
299. delay(2000);
300.
301. break;
302. }
303. // else user pressed new container for dispense
304. // TODO: set LED status for dispense - Y3
305. setLED(255, 255, 0);
306.
307. dispense();
308. break;
309.
310. }
311. // invalid container
312. else {
313. Serial.println("invalid container");
314. // TODO: set LED status for invalid container - Y5
315. setLED(255, 0, 255);
316. delay(2000);
317. if (qr.available()){
318. while (qr.available()){

319. int t = qr.read();
320. delay(5);
321. }
322. }
323.
324. break;
325. }
326. }
327. }
328.
329. }
330.
331. void dispense() {
332. Serial.println("DISPENSING");
333. // return;
334. servoD.attach(servoD_pin);
335. servoD.write(0); // rotate CW at full speed
336. delay(2500);
337. servoD.detach();
338. }
339.
340. void retrieve() {
341. Serial.println("RETRIEVING");
342. // return;
343. for (pos = 0; pos <=110; pos++){
344. servoR.write(pos);
345. delay(10);
346. }
347. for (pos = 110; pos >= 0; pos--){
348. servoR.write(pos);
349. delay(10);
350. }
351. }
352.
353. bool QRcheck() {
354. unsigned long startTime = millis(); // timer starts
355. String val = "";
356. while (millis() - startTime < timeout){
357. if (qr.available()){
358. Serial.println("reading QR");
359. // String val = "";
360. while (qr.available()){
361. int input = qr.read();
362. val += input;
363. delay(5);
364. }

365. Serial.println(val);
366. if (val.length() > 4 || val == qr1 || val == qr2 || val == qr3) {
367. Serial.println("QR successfully read");
368. return true;
369. }
370. break;
371. }
372. }
373. Serial.println("timed out");
374. return false;
375. }
376.
377. void setLED(int x, int y, int z){
378. analogWrite(a0, x);
379. analogWrite(a1, y);
380. analogWrite(a2, z);
381. }

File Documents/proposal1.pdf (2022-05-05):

# ECE 445 Project Proposal

Henry Guan (henryg2)
John Kim (jaehank2)
Ariocie Liang (arliang2)
February 10, 2022

## Introduction

Problem:
Good2Go (G2G) containers are used all throughout dining halls at U of I for individuals wanting to take their food to go. The program allows you to trade in an old container for a redeemable wooden token, where that token can then be used to trade for a new container. The current process for exchanging containers for tokens and tokens for new containers lacks a unified system across campus, and relies on human supervision and interaction. This proves to be a hassle for both parties that handle the process since it is too simple to have any one person be assigned to it, but occurs often and spontaneously enough to become bothersome. We believe that this entire process can be streamlined and improved with mechanical assistance

Solution:
Our solution involves an automated token and container exchange machine that will serve two key functions:
1. Have a digital token, that upon deposit, returns a clean container.
2. Accept a used container, generating a token or a clean container.

The goal here is to make the process semi-autonomous by removing the human to human interaction and also allow users to directly swap old containers with new ones without the need of exchanging them for tokens. This will improve the efficiency, simplicity, and performance speed of the Good2Go container system.
To do so, the system will require sensors to detect validity of the containers and the tokens. It will also have a screen display and buttons to receive user input. Lastly the microcontroller and motors will be used to process the internal state of the machine and execute the actions necessary to receive old containers, output new ones and generate a token.
The sensors are the main replacement of human to human interaction, as they are responsible for authenticating valid containers and tokens. Each container has its QR code scanned and weight measured; containers that are overweight or are missing valid QR codes are rejected. Wooden tokens will be replaced with virtualized tokens stored in a magnetic swipe card. A card reader identifies each user. A screen display and a series of buttons are used to inform the machine of the user input. Once a user deposits an old container, they will be able to select to receive a new container or a token. The microcontroller will then take this input from the user and will activate the motors to dispense and receive Good2Go containers. The motors will be placed to allow accurate delivery of only a single container at a time, which is further described in the diagram below as well as under the Subsystem Overview.

### OVERALL DESIGN


Visual Aid:

USED CONTAINER DEPOSIT MECHANISM

CLEAN CONTAINER DISPENSING MECHANISM

## High-level Requirements List:

1. Deliver the entire process (from receiving container/token to dispensing a new one) in less than 15 seconds
2. Dispense exactly one new container at a time indefinitely without any jamming
3. Accurately detect invalid containers that are overweight by more than 30 grams compared to the base weight so that containers holding too much food waste are rejected

## Design

Block Diagram:


## Subsystem Overview:

Initial State: in its initial state, the machine will be waiting for user input for either an {old container} or a {token}

### 1. UI Subsystem: display screen and buttons

The display screen along with the button is used to guide the user into selecting one of the two options. The first selection is {old container} and {token} which is used to inform the machine what it’s supposed to expect from the user. In the case of the {token}, the machine will read from the card swipe. The next option that will be displayed is {new container} and {token} which occurs in the event the user returns an old container. Based on the input, the machine will return either a new container or update the token info from the swiped card.

### 2. Sensing Subsystem: scale, card reader, camera

QR scanner to identify valid containers by reading the food container ID and a wifi module to send it over to the microcontroller. If it is an invalid ID, the machine returns to its initial state. Otherwise, the machine will dispense either a {new container} or generate a {token}
Scale to measure weight so that once it exceeds {container weight + constant}, the machine will not accept the container and will return to its initial state. If the weight is within the threshold, the machine will dispense either a {new container} or generate a {token}
Card Swipe is used to process digital coins instead of physical ones. Each card will hold information of the number of tokens and will get updated for every swipe. If a card swipe is read from the initial state, the machine will dispense a new container

### 3. Control: motors and microcontroller

An ATMega328 microcontroller will keep track of the state transitions and will also be responsible for activating different motors and reading data from the scale, token as well as the food container ID. From the initial state (old container, token), if the user inputs an old container, the microcontroller will take input from the scale and activate the motor to receive the returned old container, and then wait for further user input for {new container} or a {token}. Otherwise if the user selects a token, the microcontroller will process the token and activate the motors to dispense a new container. Motors will be wired to a pair of arms near the opening of where the user can place an old container. It will be placed on the same surface as the scale (on the bottom of the old container) so that once the motors are activated, it lifts up and acts as the pushing mechanism to deposit the old containers. A different set of motors wired to two arms (spaced for a single container) will also be used to dispense new containers. Only a single container will be preloaded in between the arms, with the rest being loaded behind this single container at an angle. Upon the activation of the motors, the first arm closest to the drop chute will open first, dispensing the container. That arm will then close, followed by the second arm opening, allowing one container through. That barrier will then close, completing the process of preloading another container that's ready to dispense.

### 4. Power Subsystem: AC/DC converter and voltage regulator

Takes in power from a conventional wall outlet and outputs regulated voltage specified in our design to properly power all components.

## Subsystem Requirements:

### 1. UI Subsystem:

The UI subsystem includes a display screen with a 10 inch display size using a power supply of 3.3V. The only input the display screen takes is from the power supply and from the microcontroller so as to give the user an option to select a specific action the machine needs to perform. This includes a selection between an {old container} and {token} to inform the machine what it should expect to read from the user. The next selection is between two outputs including {new container} and {token} for returning an old container. 10mm wide push buttons with switch functions (ON and OFF) are used to read the user choice, which is then fed back to the microcontroller to carry out the next course of action.

Requirements:
- Clear and readable text output to screen with specific message defined by microcontroller
- The microcontroller must detect the ON and OFF switch functions of the buttons
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

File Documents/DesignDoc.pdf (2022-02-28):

# ECE 445 Design Document

TA: Akshatkumar Sanatbhai Sanghvi Henry Guan (henryg2)
John Kim (jaehank2)
Ariocie Liang (arliang2)
February 24, 2022

### Introduction

We will build Good2Go Automated Token Exchanger (GATEr) for the people that want to take food out from the dining hall and eat it wherever they go. The people who take food out from the dining hall using the current system for Good2Go (G2G) face a big problem when it comes to the number of steps one has to take in order to obtain a brand new G2G container. Also, the current state of G2G is that a person wanting to get a G2G container will have to wait in the same line as other people who just want to eat in the dining hall. This results in longer time spent and having unnecessary human to human interactions. GATEr streamlines the process of obtaining a brand new G2G container by removing human interaction
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

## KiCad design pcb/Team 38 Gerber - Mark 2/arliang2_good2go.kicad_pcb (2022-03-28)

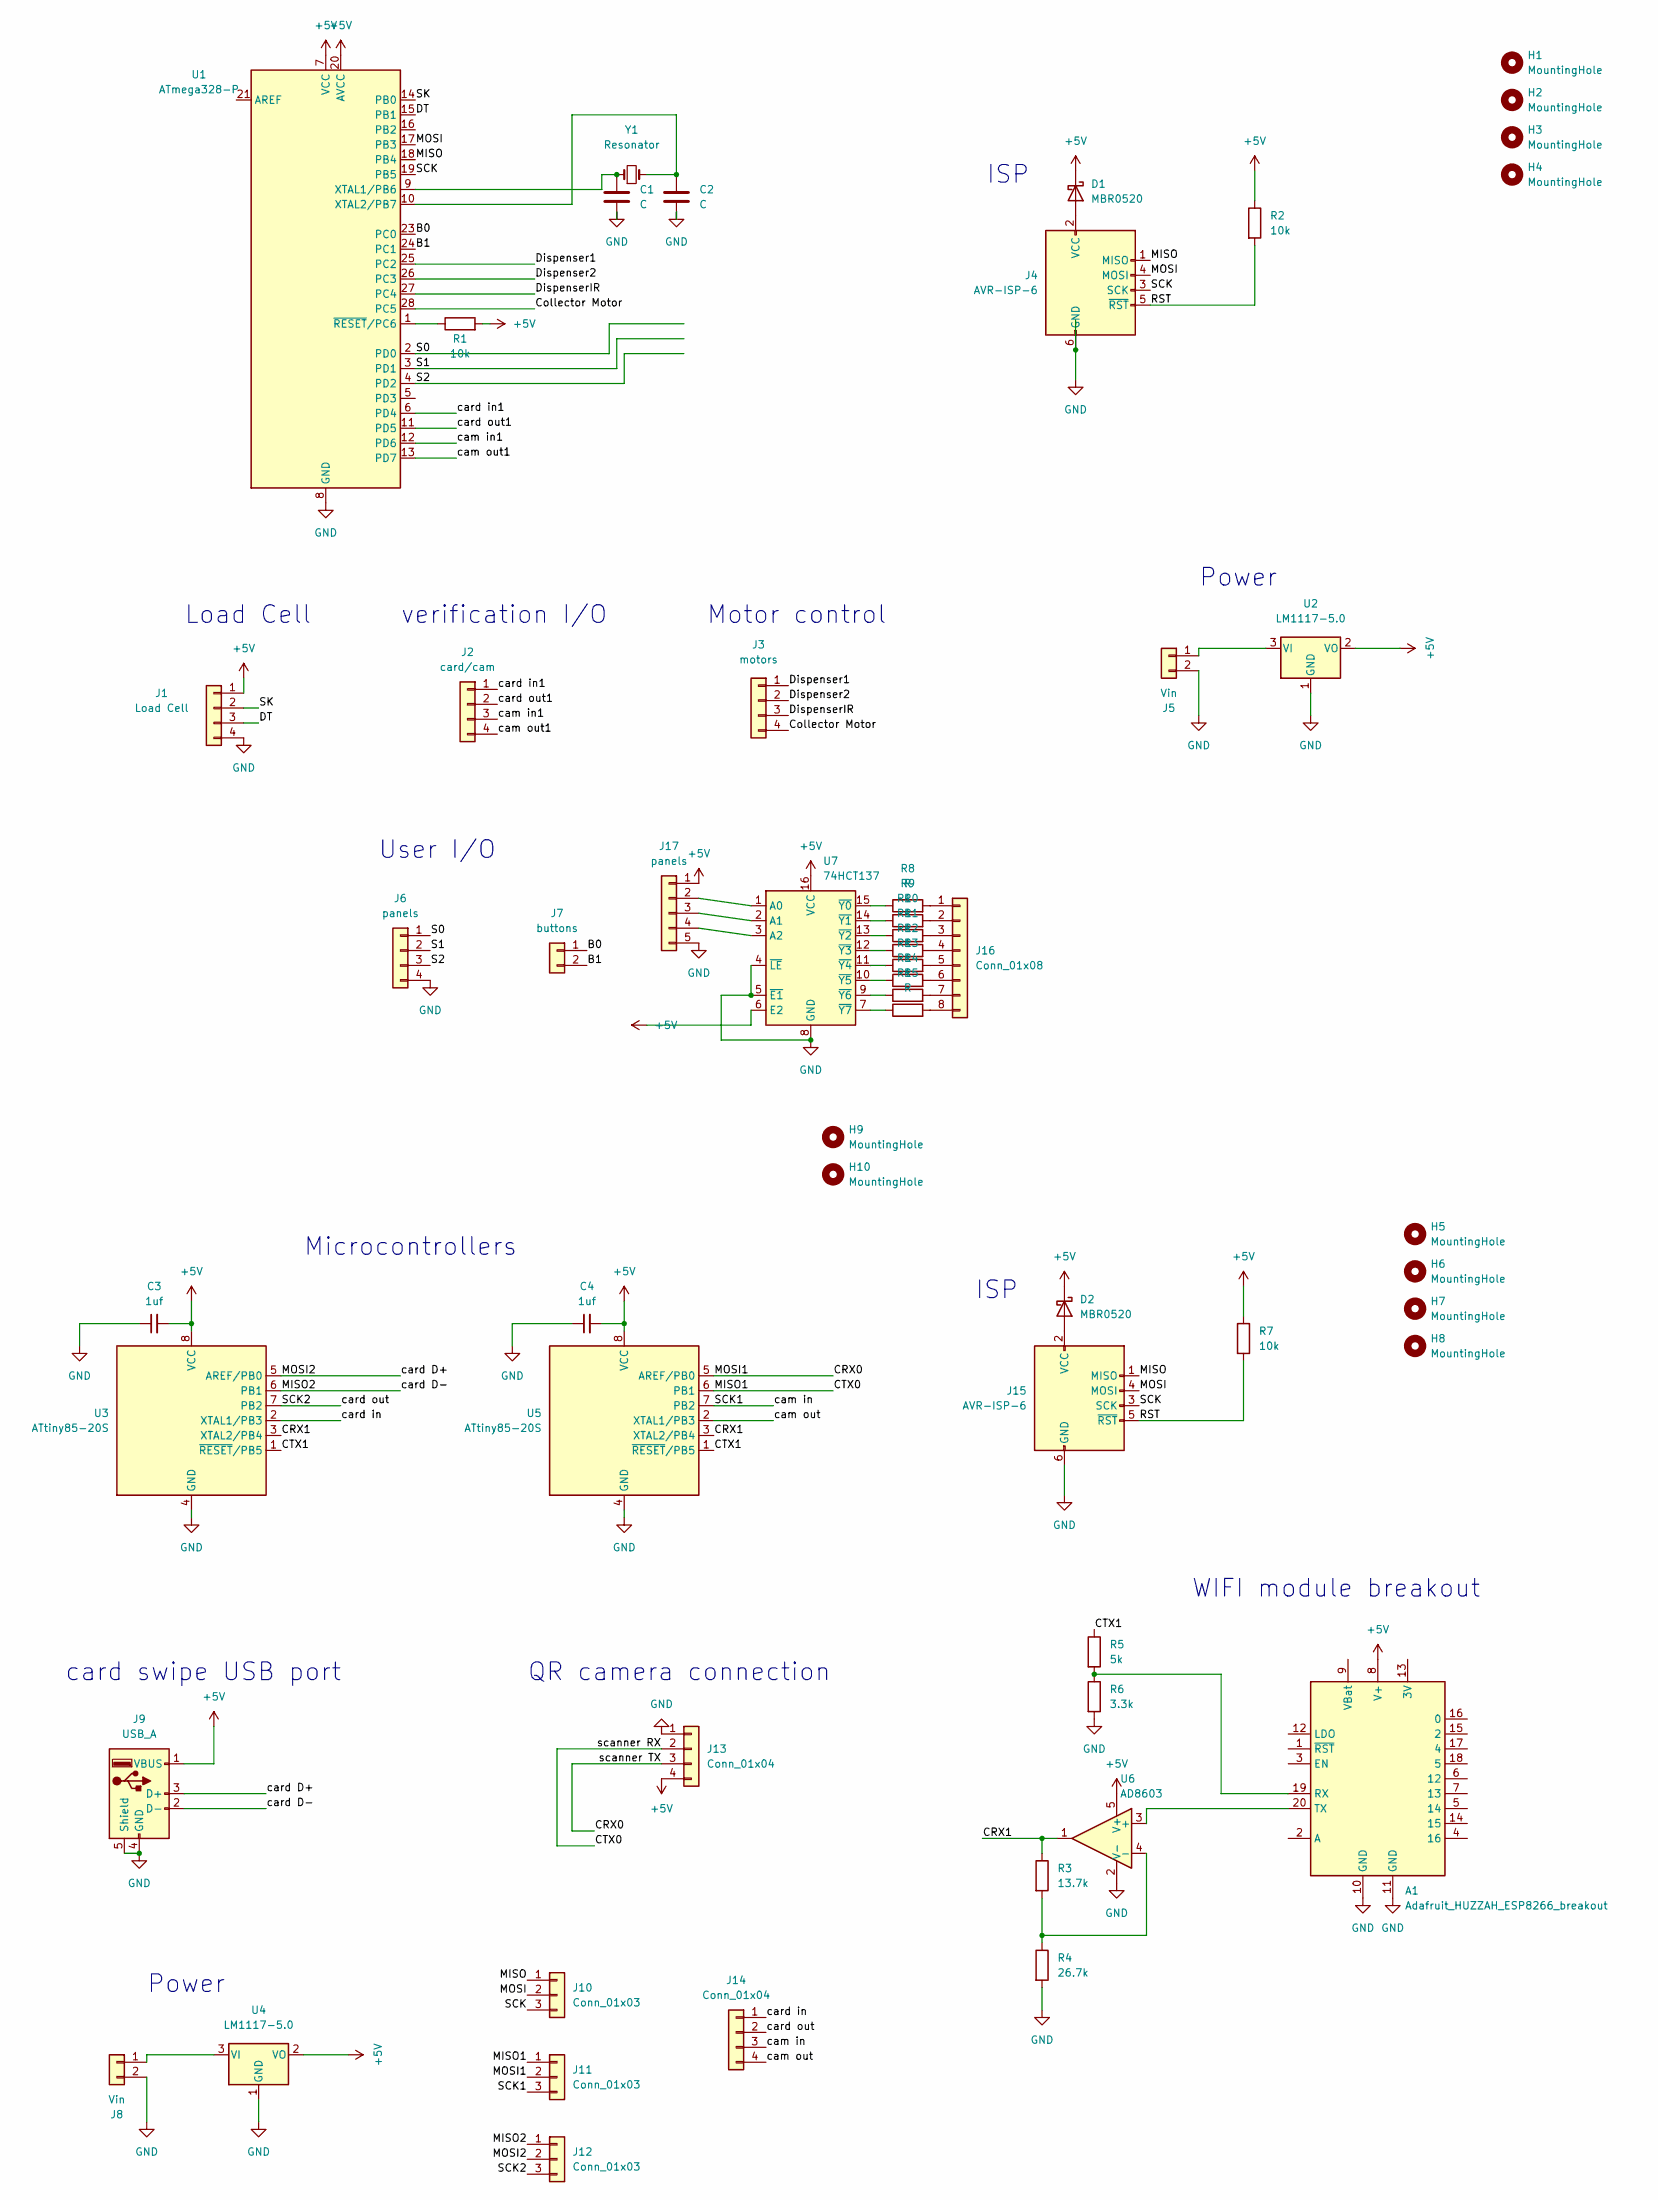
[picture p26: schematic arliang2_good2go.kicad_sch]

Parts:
A1: Adafruit_HUZZAH_ESP8266_breakout; Adafruit_HUZZAH_ESP8266_breakout_WithMountingHoles
C1, C2: C; C_0805_2012Metric_Pad1.18x1.45mm_HandSolder
C3, C4: 1uf; C_0805_2012Metric_Pad1.18x1.45mm_HandSolder
D1, D2: MBR0520; D_SOD-123
H1, H2, H3, H4, H5, H6, H7, H8, H9, H10: MountingHole; MountingHole_3.2mm_M3
J1: Load Cell; Molex_KK-254_AE-6410-04A_1x04_P2.54mm_Vertical
J2: card/cam; Molex_KK-254_AE-6410-04A_1x04_P2.54mm_Vertical
J3: motors; Molex_KK-254_AE-6410-04A_1x04_P2.54mm_Vertical
J4, J15: AVR-ISP-6; IDC-Header_2x03_P2.54mm_Vertical
J5, J8: Vin; Molex_KK-254_AE-6410-02A_1x02_P2.54mm_Vertical
J6: panels; Molex_KK-254_AE-6410-03A_1x03_P2.54mm_Vertical
J7: buttons; Molex_KK-254_AE-6410-02A_1x02_P2.54mm_Vertical
J9: USB_A; USB_A_Stewart_SS-52100-001_Horizontal
J10, J11, J12: Conn_01x03; Molex_KK-254_AE-6410-03A_1x03_P2.54mm_Vertical
J13, J14: Conn_01x04; Molex_KK-254_AE-6410-04A_1x04_P2.54mm_Vertical
J16: Conn_01x08; Molex_KK-254_AE-6410-08A_1x08_P2.54mm_Vertical
J17: panels; Molex_KK-254_AE-6410-05A_1x05_P2.54mm_Vertical
R1, R2: 10k; R_0805_2012Metric_Pad1.20x1.40mm_HandSolder
R3: 13.7k; R_0805_2012Metric_Pad1.20x1.40mm_HandSolder
R4: 26.7k; R_0805_2012Metric_Pad1.20x1.40mm_HandSolder
R5: 5k; R_0805_2012Metric_Pad1.20x1.40mm_HandSolder
R6: 3.3k; R_0805_2012Metric_Pad1.20x1.40mm_HandSolder
R7: 10k; C_0805_2012Metric_Pad1.18x1.45mm_HandSolder
R8, R9, R10, R11, R12, R13, R14, R15: R; R_0805_2012Metric_Pad1.20x1.40mm_HandSolder
U1: ATmega328-P; DIP-28_W7.62mm_Socket
U2, U4: LM1117-5.0; SOT-223
U3, U5: ATtiny85-20S; SOIC-8W_5.3x5.3mm_P1.27mm
U6: AD8603; TSOT-23-5
U7: 74HCT137; DIP-16_W7.62mm
Y1: Resonator; Crystal_HC49-U_Vertical

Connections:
+5V: A1.8 (V+), C3.2, C4.2, D1.1 (K), D2.1 (K), J1.1, J9.1 (VBUS), J13.4, J17.1, R1.2, R2.1, R7.1, U1.7 (VCC), U1.20 (AVCC), U2.2 (VO), U3.8 (VCC), U4.2 (VO), U5.8 (VCC), U6.5 (V+), U7.6 (E2), U7.16 (VCC)
/B0: J7.1, U1.23 (PC0)
/B1: J7.2, U1.24 (PC1)
/CRX0: J11.2, J13.3, U5.5 (AREF/PB0)
/CRX1: R3.1, U3.3 (XTAL2/PB4), U5.3 (XTAL2/PB4), U6.1
/CTX0: J11.1, J13.2, U5.6 (PB1)
/CTX1: R5.1, U3.1 (~RESET/PB5), U5.1 (~RESET/PB5)
/Collector Motor: J3.4, U1.28 (PC5)
/DT: J1.3, U1.15 (PB1)
/Dispenser1: J3.1, U1.25 (PC2)
/Dispenser2: J3.2, U1.26 (PC3)
/DispenserIR: J3.3, U1.27 (PC4)
/MISO: J4.1 (MISO), J10.1, J15.1 (MISO), U1.18 (PB4)
/MISO2: J9.2 (D-), J12.1, U3.6 (PB1)
/MOSI: J4.4 (MOSI), J10.2, J15.4 (MOSI), U1.17 (PB3)
/MOSI2: J9.3 (D+), J12.2, U3.5 (AREF/PB0)
/RST: J4.5 (~RST), J15.5 (~RST), R2.2, R7.2
/S0: J6.1, U1.2 (PD0)
/S1: J6.2, U1.3 (PD1)
/S2: J6.3, U1.4 (PD2)
/SCK: J4.3 (SCK), J10.3, J15.3 (SCK), U1.19 (PB5)
/SCK1: J11.3, J14.3, U5.7 (PB2)
/SCK2: J12.3, J14.2, U3.7 (PB2)
/SK: J1.2, U1.14 (PB0)
/cam in1: J2.3, U1.12 (PD6)
/cam out: J14.4, U5.2 (XTAL1/PB3)
/cam out1: J2.4, U1.13 (PD7)
/card in: J14.1, U3.2 (XTAL1/PB3)
/card in1: J2.1, U1.6 (PD4)
/card out1: J2.2, U1.11 (PD5)
GND: A1.10 (GND), A1.11 (GND), C1.2, C2.2, C3.1, C4.1, J1.4, J4.6 (GND), J5.2, J6.4, J8.2, J9.4 (GND), J9.5 (Shield), J13.1, J15.6 (GND), J17.5, R4.2, R6.2, U1.8 (GND), U1.22 (GND), U2.1 (GND), U3.4 (GND), U4.1 (GND), U5.4 (GND), U6.2 (V-), U7.4 (~LE), U7.5 (~E1), U7.8 (GND)
unnamed: A1.19 (RX), R5.2, R6.1
unnamed: A1.20 (TX), U6.3 (+)
unnamed: C1.1, U1.9 (XTAL1/PB6), Y1.1
unnamed: C2.1, U1.10 (XTAL2/PB7), Y1.2
unnamed: D1.2 (A), J4.2 (VCC)
unnamed: D2.2 (A), J15.2 (VCC)
unnamed: J5.1, U2.3 (VI)
unnamed: J8.1, U4.3 (VI)
unnamed: J16.1, R8.2
unnamed: J16.2, R9.2
unnamed: J16.3, R10.2
unnamed: J16.4, R11.2
unnamed: J16.5, R12.2
unnamed: J16.6, R13.2
unnamed: J16.7, R14.2
unnamed: J16.8, R15.2
unnamed: J17.2, U7.1 (A0)
unnamed: J17.3, U7.2 (A1)
unnamed: J17.4, U7.3 (A2)
unnamed: R1.1, U1.1 (~RESET/PC6)
unnamed: R3.2, R4.1, U6.4 (-)
unnamed: R8.1, U7.15 (~Y0)
unnamed: R9.1, U7.14 (~Y1)
unnamed: R10.1, U7.13 (~Y2)
unnamed: R11.1, U7.12 (~Y3)
unnamed: R12.1, U7.11 (~Y4)
unnamed: R13.1, U7.10 (~Y5)
unnamed: R14.1, U7.9 (~Y6)
unnamed: R15.1, U7.7 (~Y7)

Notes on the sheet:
Power
card swipe USB port
WIFI module breakout
QR camera connection
verification I/O
Motor control
User I/O
Microcontrollers
ISP
Load Cell

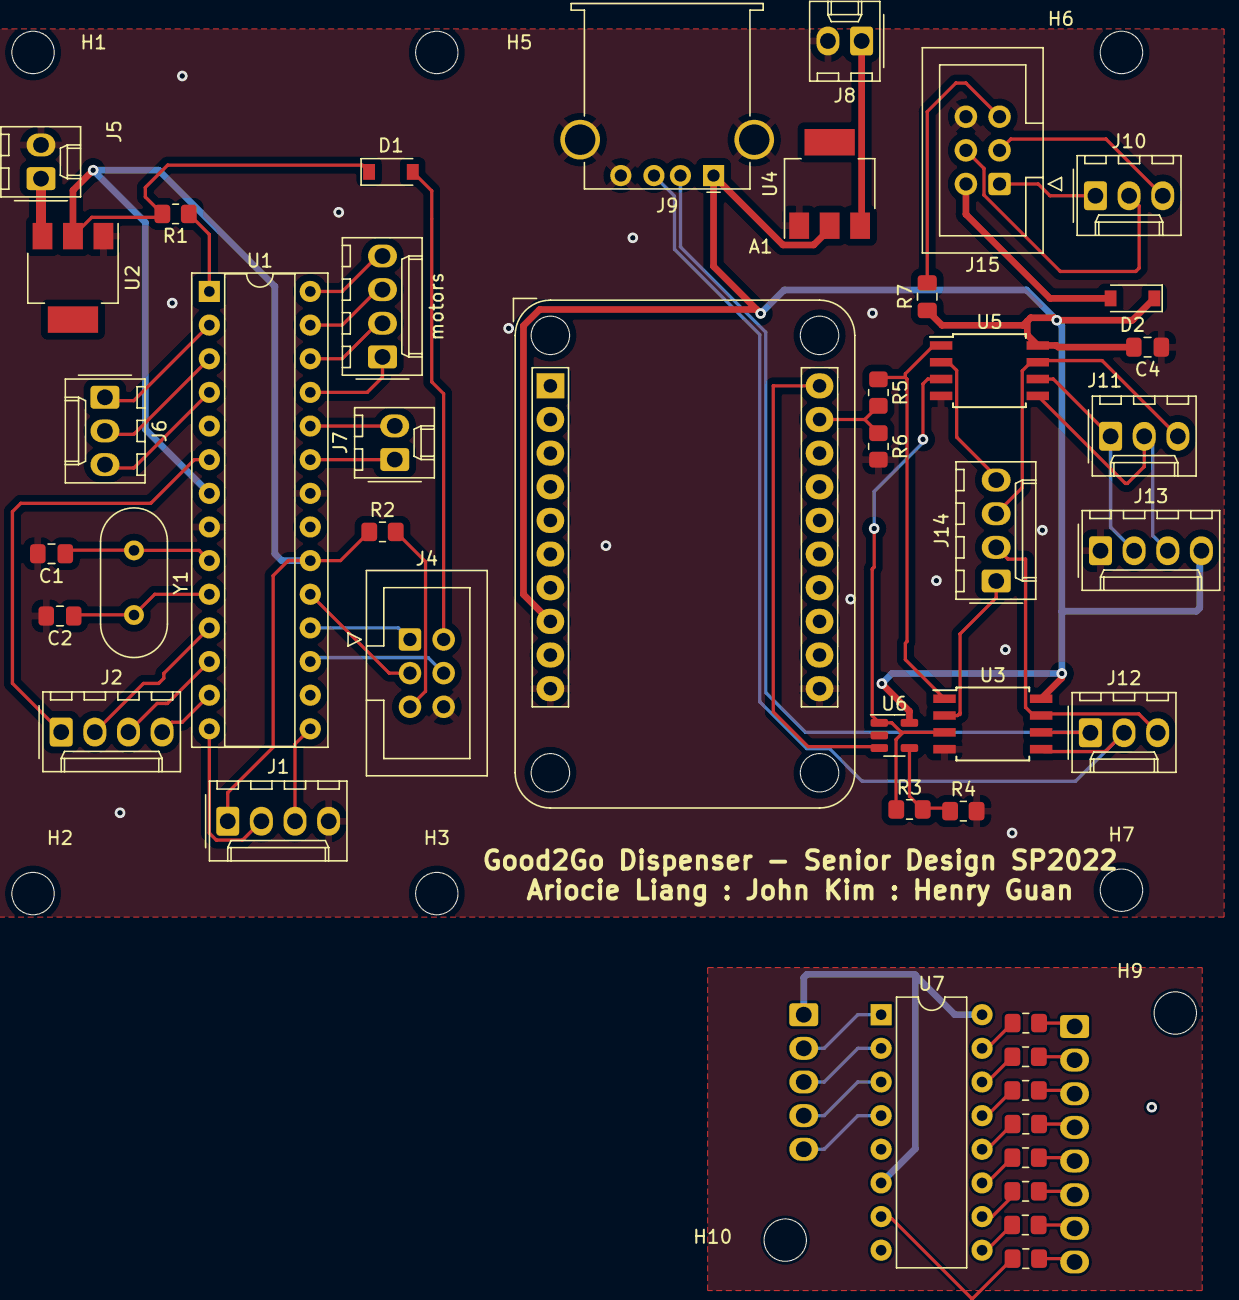
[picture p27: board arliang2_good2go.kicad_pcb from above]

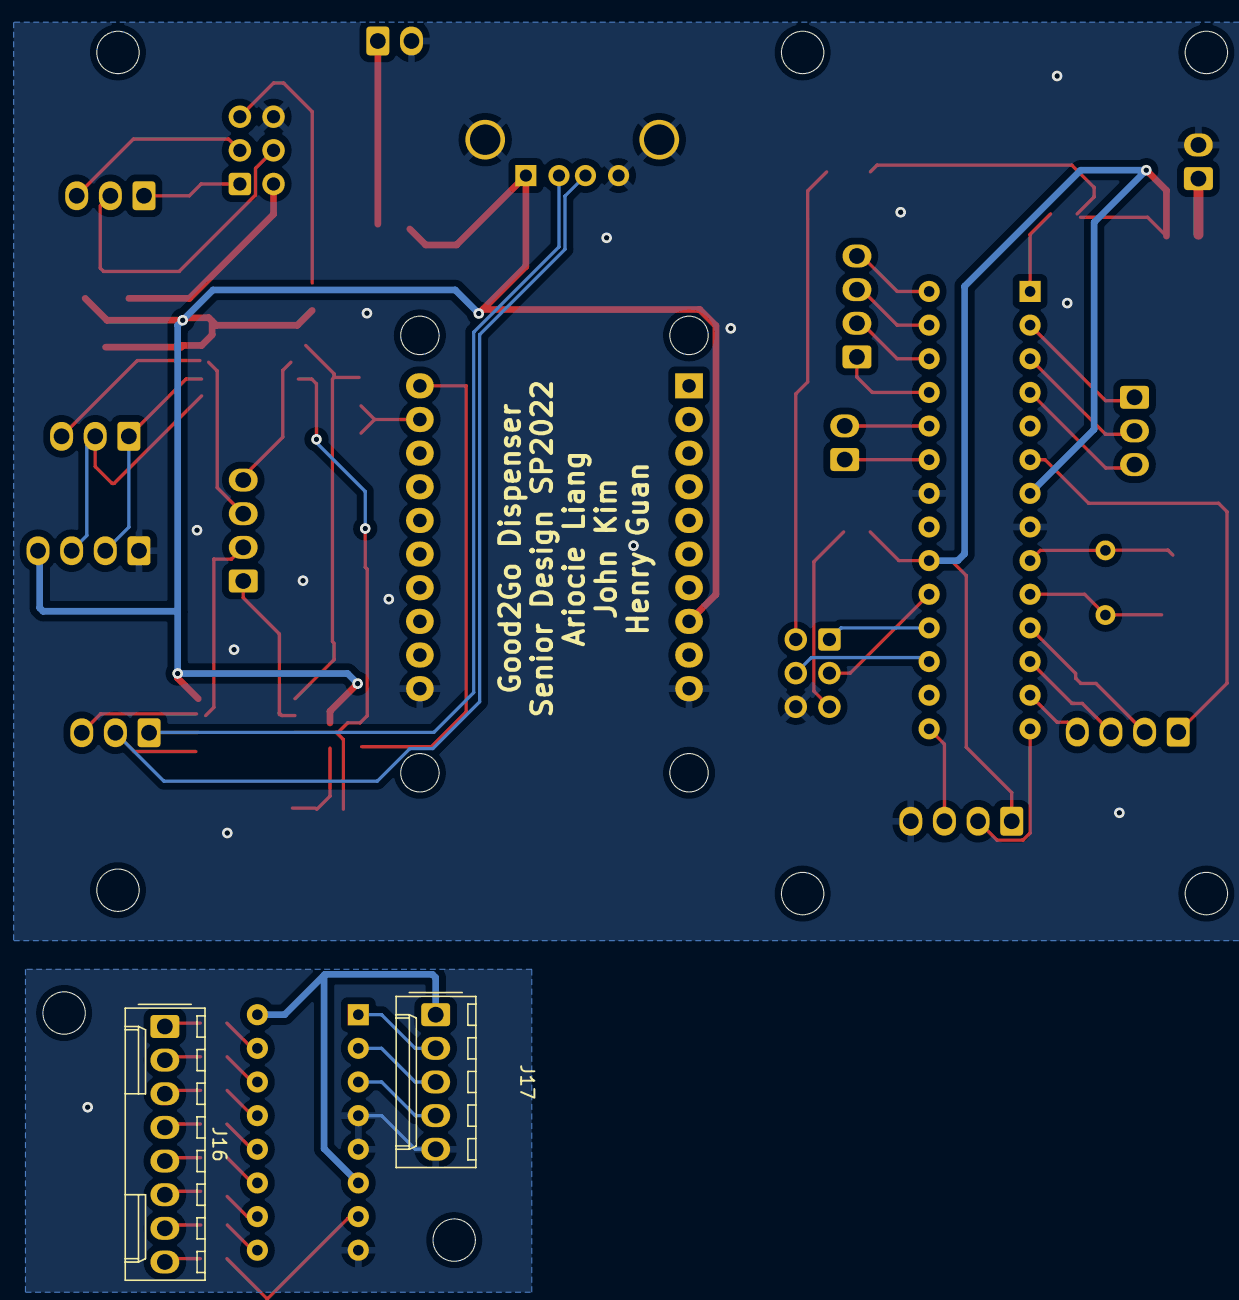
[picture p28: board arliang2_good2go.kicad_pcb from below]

Board: 2 copper layers, 54 parts (2 on the bottom side), 60 nets.

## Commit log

2022-02-08 added RFA from Web Board
2022-03-28 PCB first draft - SMD
    [arliang2_good2go-B_Cu.gbl, arliang2_good2go-B_Mask.gbs, arliang2_good2go-B_Paste.gbp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]
